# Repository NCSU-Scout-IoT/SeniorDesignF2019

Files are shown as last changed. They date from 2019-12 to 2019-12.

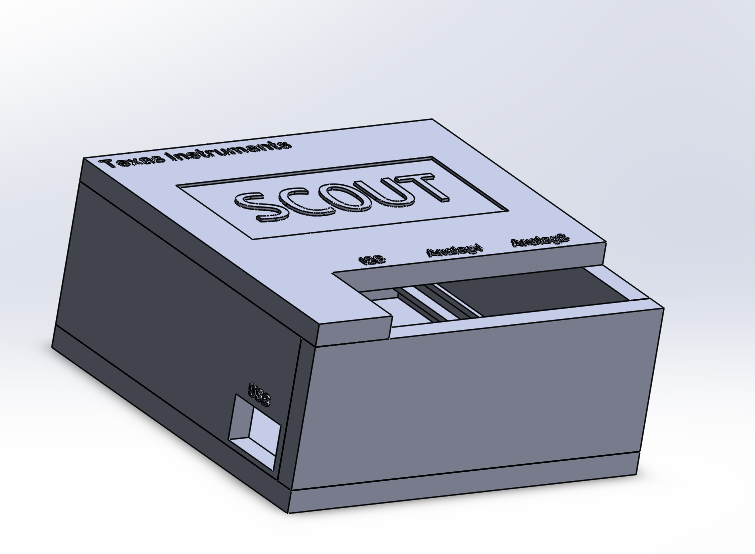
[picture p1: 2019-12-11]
Hardware Files/Enclosure Design/Picture.PNG

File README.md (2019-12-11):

# Scout IoT development kit
Table of Contents

Final Documents
- User Guides
  - QuickStart Guide
  - ESP32 AT Commands User Guide
  - Mobile Application User Guide
  - Software Guides
- Final Designs
  - Final Product Requirements
  - Final Test Plan with Results
  - Detailed Design Document
  - Final Bill of Materials
  - Final Product Price
  
Software Files
 - ESP32 Firmware
- Software Examples
- Mobile App Files

Hardware Files 
- EAGLE files
- Schematic and Board Layouts
- Enclosure 
  - SolidWorks Parts and Assembly
  - STL files

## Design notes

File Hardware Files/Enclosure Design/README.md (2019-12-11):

# Enclosure
Open STL files in Windows 3D Viewer

or

Open SLDASM in SolidWorks to view enclosure.

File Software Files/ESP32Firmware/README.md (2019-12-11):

# ESP32 firmware

File used in Arduino IDE

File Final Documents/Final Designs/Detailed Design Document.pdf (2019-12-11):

# Scout IoT Development Kit

## Sponsor: Mark Easley

Team Members: Emily Pigeon, Jacob Sparks, Caleb Snow,

## Qiang Yang

December 11, 2019

### Table of Contents

Abstract | 4
Background | 5
Requirements | 6
Architectural Diagrams | 7
User Operation | 8
Subsystems | 10
Power Supply Subsystem | 10
PCB Design/CAD Tool Selection | 12
Microcontroller | 15
Sensors | 17
Sensor Software | 18
ESP32-WROOM-32 | 19
Cloud Services | 24
Alternatives | 24
MQTT Protocol | 26
Mobile Application Builder | 27
Alternatives | 27
Conclusion | 29

### Table of Figures

Figure 1 - System Architecture | 7
Figure 2 - User Operation Diagram | 8
Figure 3 - Power Subsystem Block Diagram | 10
Figure 4 - Micro USB 2.0 | 11
Figure 5 - Block diagram for TI Buck Converter IC | 11
Figure 6 - Circuit diagram for power system | 12
Figure 7 - MSP430FR5994 library imported in Eagle | 13
Figure 8 - Eagle User Interface for Schematic Design Window | 14
Figure 9 - MSP430 Simplified Block Diagram | 15
Figure 10 - MSP430 Detailed Block Diagram | 16
Figure 11 - Sensor Subsystem Block Diagram | 17

Figure 12 - Grove Universal 4-pin connector | 17
Figure 13 - BoosterPack pinout | 18
Figure 14 - ESP32-WROOM-32 SMD package | 19
Figure 15 - Detailed physical dimensions of the ESP32-WROOM-32 | 19
Figure 16 - ESP32-WROOM-32 pinout | 20
Figure 17 - ESP32 detailed schematic | 21
Figure 18 - Wi-Fi software flowchart | 22
Figure 19 - Bluetooth software flowchart | 23
Figure 20 - MQTT flowchart | 26

## Background

As the demand for interconnectivity between devices grows, more and more developers are entering the IoT (Internet of Things) market. These developers are often looking for an IoT kit that can allow them to enter in to this market as fast as possible, as cheaply as possible, and with less and less technical knowledge. This design offers developers a relatively inexpensive and simple way to develop IoT-capable devices with only some embedded C programming skills required.
For developers that have some experience using either TI BoosterPacks or Seeed Grove modules, this kit will stand out as it can accept sensors in either format. This kit can utilize analog Grove sensors, digital Grove sensors, and TI BoosterPacks simultaneously. This gives the developer the ability to choose from several hundred different sensors and a vast amount of combinations. Accepting both the BoosterPack and Grove module formats gives this design more versatility, without requiring any more technical experience.

## Requirements

version 3.1

### 1. General Functional and Mechanical Requirements

1.1. Product MUST have an open-source PCB layout and bill of materials
1.2. Product MUST have a Quick Start Guide paper insertion with a pinout diagram, instructions on how to obtain software demos and PCB layout, and a list of materials.
1.3. Product MUST transmit sensor data via Wi-Fi to cloud service at no less than 1Mbps
1.4. Product MUST transmit sensor data via BLE, at least 1Mbps, to the mobile phone app
1.5. Product MUST cost under $50 to manufacture
1.6. Product MUST include a plastic chassis with tool-less assembly and disassembly

### 2. User Interface Requirements

2.1. Product MUST have a user-programmable LED and push button
2.2. Product MUST have an LED to display Wi-Fi connection status
2.3. Product MUST have power status LED

### 3. Hardware Requirements

3.1. Product MUST use micro-USB connector for power
3.2. Product MUST use TI MCU
3.3. Product MUST have clear silkscreen labeling of important board markings for users
3.4. Product MUST have headers for hardware debugger (MSP-FET)
3.5. Product MUST include 3 Seeed Grove connectors, 2 designed for analog signals and 1 for digital I²C signals

### 4. Software Requirements

4.1. Product MUST have at least 5 code examples with documentation
4.2. Code examples MUST be available for Code Composer Studio
4.3. Code examples MUST include blinking LED, button input, and wireless communication initialization
4.4. Cloud Service MUST show data from all sensors and define which sensor ports are not in use.
4.5. Mobile Application MUST show real-time sensor readings

## System Drawing

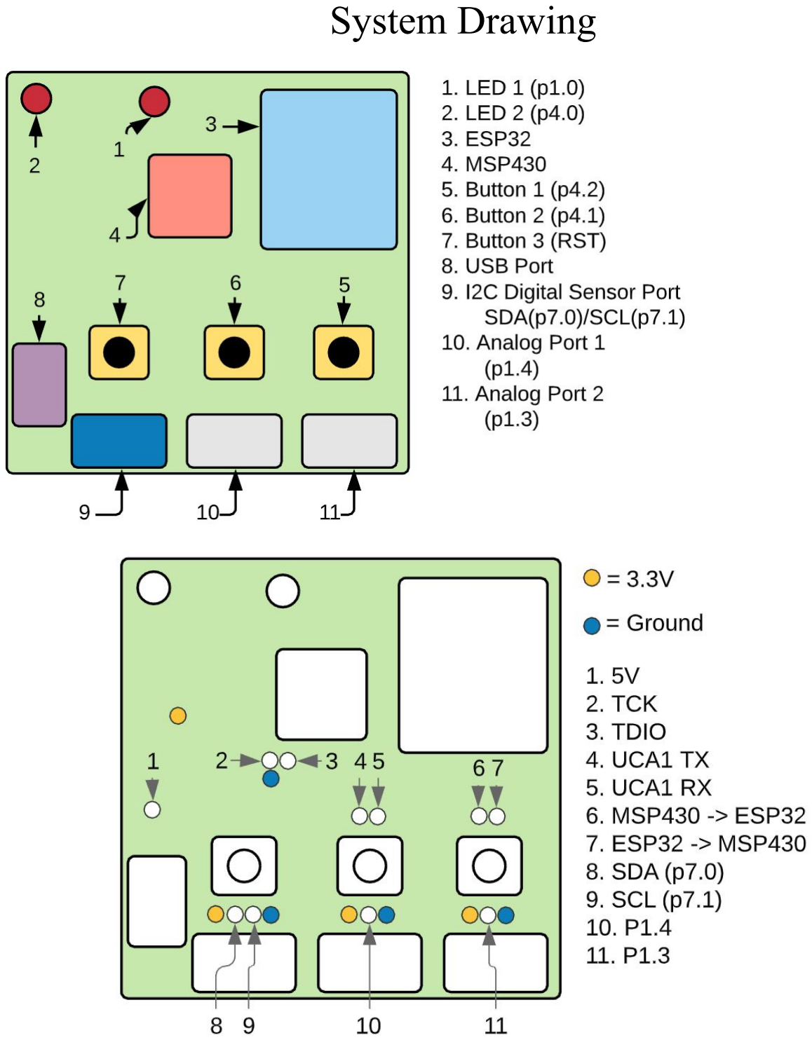
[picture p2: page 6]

## Operational Diagram

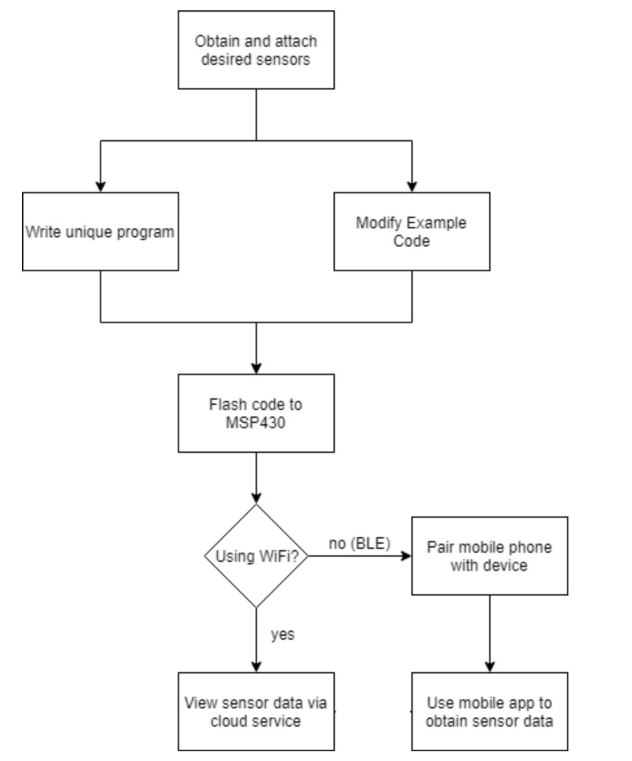
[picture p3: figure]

Since this kit is aimed at aspiring developers, the user operation will require a limited knowledge of embedded systems coding. We will be providing example code with functions that connect to a Wi-Fi network and send data over either connection, but for specific applications beyond these simple starting points, some expertise will be required.
The user will view and analyze sensor data via our chosen cloud service, Microsoft Azure IoT Hub. The sensor data could also be analyzed on the chip, and actions related to the specific application could be taken without direct user intervention, e.g. using a general-purpose I/O to activate an actuator.

## Detailed System Block Diagrams

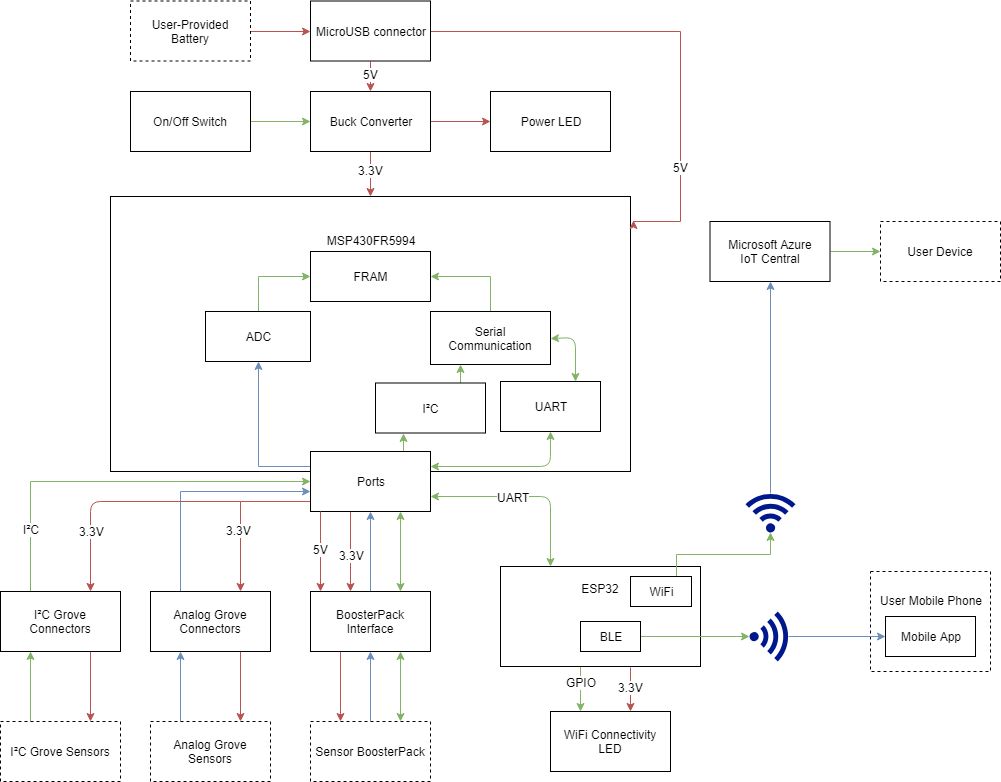
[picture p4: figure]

The two key blocks in our architecture are the MSP430 microcontroller and the ESP32 network processor. Part of the reason we decided on the ESP32 can be seen in our diagram - ease of connection. Only a single UART connection will be necessary for the MSP430 to communicate with the ESP32 and, therefore, the cloud service and user. As can be seen in the legend, green arrows are digital information, either in the I²C format or UART on our device, and in other forms on the user devices. Red arrows represent power that our power system will provide for and blue arrows show analog signals, either sensor data to be sampled by the MSP430’s analog-to-digital converter (ADC) or wireless signals.

Blocks shown with a dotted border are subsystems that are critical to the full function of our device but will be provided by the user. Any power source that conforms to the MicroUSB standard could be used in place of a battery, provided it can fully supply the power required. This means that a user could instead use an AC/DC converter to power the device from the wall if they were so inclined.
The sensor choice is up to the user, and we provide two methods of connection: Grove sensors and BoosterPacks. The sensors will communicate with the MSP430 either through an analog signal or a serial digital communications protocol. Two of the Grove connectors will use the I²C protocol and the other two will send an analog signal to be processed by the MSP430’s ADC.
The ESP32 will forward sensor data to Microsoft Azure where it will be processed and visible to the user through any device. The forwarding will either happen through Wi-Fi, where it will connect directly to Microsoft Azure through the Internet, or through Bluetooth Low-Energy (BLE) via a mobile phone application.

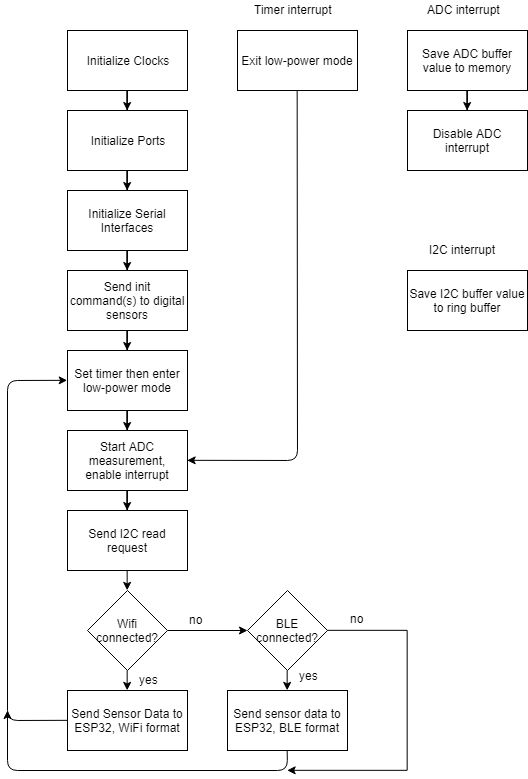
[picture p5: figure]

The overall format of the software
provided as an example is a loop wherein the
device stays in a low-power mode for as long as possible. After initialization, the main loop consists of enabling interrupts, getting sensor data through those interrupts, forwarding the data to the ESP32, then reentering low-power mode.
The messages sent to the ESP32 will depend on whether the device is connected to a wireless network with access to Microsoft Azure or paired via Bluetooth to the mobile app.

## System Design and Component Selection Alternatives

Microcontroller

Alternatives to the MSP430FR5994 include the MSP432P401Y, a more expensive 32-bit MCU with an ARM Cortex CPU and a clock of up to 48MHz, and the less expensive MSP430FR2355. We chose the MSP430FR5994 due to its value and ability to perform the functions necessary for an IoT development kit. The larger number of ADC and I²C channels and larger memory made it the ideal choice when compared to the lower-priced FR2355. The MSP432401Y’s higher-powered CPU would not be fully utilized by our applications, and since it had almost equivalent I/O capabilities with the FR5994, it was ruled out.

Microcontroller | Price | I²C | ADC channels
MSP430FR5994 | $3.60 | 3 | 20
MSP430FR2355 | $2.40 | 2 | 12
MSP432P401Y | $5.40 | 3 | 12

Network Processor

Alternatives to the ESP32 included the TI CC3100MOD, a Wi-Fi only network processor made with cooperation with MSP430 microcontrollers in mind. However, its higher price, lack of Bluetooth capability, and more complicated proprietary API made the ESP32 the better choice. Espressif also makes cheaper network processors such as the ESP8285. These would have served well for our application if Wi-Fi had been our only method of communication, but the added benefit of Bluetooth made the ESP32 worth the extra cost.
Network Processor | Cost | Capability | Ease of use
Espressif ESP32 | $3.80 | Wi-Fi + Bluetooth | AT Commands
TI CC3100MOD | $6.99 | Wi-Fi | TI API
Espressif ESP8285 | $1.80 | Wi-Fi | AT Commands

Cloud Service

Cloud Service | Pros | Cons
Microsoft Azure IoT Hub | ● Cost: Free to sign up ● Made to be simple and easy to use for people with little cloud experience ● Provides a GUI with charts for incoming data ● Many online resources on how to set up | ● No specific online documents relating to ESP32 from Microsoft ● Less code samples
Amazon Web Service FreeRTOS | ● Partners with Espressif ● Good online documentation concerning the ESP32 ● Includes support for BLE Mobile ● Many code examples from Amazon | ● Price: Charges for data transfer, otherwise free to use ● Code intensive
Google Cloud IoT Core | ● Partners with Espressif ● Thorough overall documentation ● Many code examples from Google | ● Price: Charges by volume of data, up to 250MB free ● No online documentation about the ESP32 from Google ● Code intensive

Amazon Web Service’s FreeRTOS is a contender because Amazon is the most popular company on the market providing cloud services, which means it is well documented and will likely have many available resources for us to use in development, as well as the consumer. This particular service is directed specifically at IoT developers working with MCUs. A major benefit of this service is the BLE mobile app, but this service is still in beta testing. There is an online guide to set up service on an ESP32 Development Kit, and it is very thorough, but it also shows how labor intensive it is. The price could also pose an issue, as most of what we will be using the service for is data transfer from the device to the cloud, which means this service could be costly to us. The total cost includes many different aspects of how we use the service, so price estimation would be very difficult. In addition, during the research of this service, we could not find any examples of how the data would be displayed on the PC client, which implies that is something we’d set up ourselves. Overall, while the service is very popular and well documented, it is meant for people with a lot of experience setting up a cloud service, and we do not have enough time or resources to dedicate to using this software.

Google Cloud’s IoT Core is also a contender. Google is another reputable company but is not as established as Microsoft or Amazon when it comes to IoT applications. The service itself is extremely well documented, with many code samples in many different languages. However, there is very little documentation to be found concerning the ESP32 specifically anywhere online, and none was found from Google. Pricing is also a concern. Google charges for every message sent after a limit of 250 MB is exceeded. The IoT Core from Google would also need to use Google’s IoT Pub/Sub service, which we would also be charged for. Overall, similarly to AWS FreeRTOS, this service would be difficult to set up and could be expensive.

Our final contender is Microsoft Azure’s IoT Hub, which is Microsoft Azure’s IoT cloud service that is comparable to the previous two choices. IoT Hub can handle connection to the device, neatly displaying sensor data in graphs, and creating rules and actions concerning sensor data, such as sending an email if a sensor is tripped if used with Hub Solutions. Pricing is also very simple, as it is free to sign up with $200 credit. Considering that we will only be using one device, and likely will be under the limit, we will likely be able to use this service either free or very cheaply. Unfortunately, there isn’t documentation from Microsoft concerning the ESP32 specifically, however there are general guides to aid set up. There are thorough online guides about how to set up the software itself as well. Another potential issue with this software is that it is more limited than the previous examples, so there is not much we can control. After
comparing these cloud services, we selected Azure’s IoT Hub for its apparent ease of use and simple pricing.

Mobile App Builder

To provide clients with examples of setting up Bluetooth from the ESP32, we must select a simple mobile application builder to debug our software. To do this, we must use a quick and easy mobile application builder that can communicate through Bluetooth and accurately read back sensor data. There are many options on the market for mobile app builders, but it is important that we find one with many available online resources and support.

Mobile App Builder | Pros | Cons
Thunkable | ● No coding required ● Online tutorials with the ESP32 ● Free for public projects, offers special education prices ● Works with both iOS and Android ● Public library of projects ● Supports BLE | ● Reports of bugs ● ESP32 example uses Arduino IDE
Evothings Studio | ● Supports BLE ● Works with Android and iOS ● Completely free and open source ● Extensive BLE documentation | ● Coding in HTML5 ● No specific ESP32 examples
Android Studio | ● Reliable company ● Extensive BLE documentation ● Coding in Java or C/C++ ● Completely free | ● No specific ESP32 examples ● Only supports Android

We chose Thunkable as our sample mobile application. Because this software requires no coding, it will be much quicker to get up and running when our ESP32 is ready to be debugged. Android Studio and Evothings Studio both require the application to be built from code, which will make debugging more difficult because bugs could exist in either our mobile application or our development kit. Also, Evothings Studio requires software to be done in HTML5, which none of us have experience with. Thunkable also has a public library of apps that other developers that use the software have created. Within this library are examples of a BLE application that connects specifically to the ESP32. While both Evothings and Android have very thorough documentation of how BLE can be implemented on their platforms, neither has examples that relate to the ESP32 specifically. Finally, Thunkable, as well as Evothings, creates applications that can be used on both iOS and Android, which will allow our code to be more thoroughly tested and easier to develop. Android Studio, while being a reliable company, is not available on iOS which means we will have to have an Android phone to test.

## Hardware Design

PCB Design/CAD Tool Selection

The CAD tool chosen for the schematic and PCB design of this project is Eagle. Eagle was chosen from the selection of tools including: Altium, KiCad, Eagle, OrCad, and DipTrace. A major selection criteria in this process was design files/footprint/symbols accessibility. Creating these from scratch would be much less time-efficient than finding them online and importing them into our design tool. Eagle offered the best online support of the tools mentioned and can import files directly from the UltraLibrarian tool on Texas Instruments’ website. Any other components can be sourced from the many websites that offer libraries for Eagle.
Another consideration was the user interface. The more intuitive the interface is, the less time consuming it will be to begin using the CAD tool. Eagle’s user interface is as simple and intuitive as any of the other choices. The Eagle schematic editor includes:
- Links to a library
- Electrical rule check
- Netlist generation
- Forward/Back annotation between schematic and PCB (keeps things in sync when making changes in one or the other)
- Schematic hierarchy for the design organization
- User access to define many things like nets, wire width, clearance, etc.

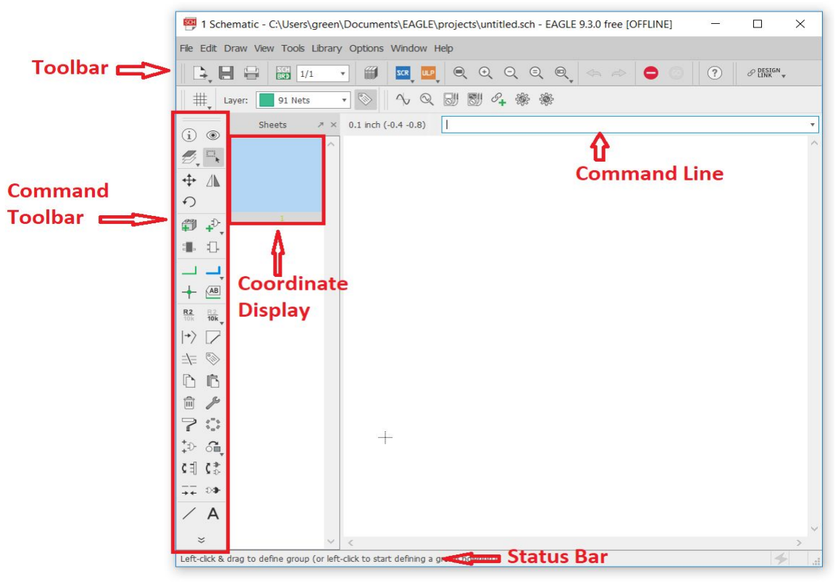
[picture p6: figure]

Figure 8 - Eagle User Interface for Schematic Design Window

Basic Circuit Design

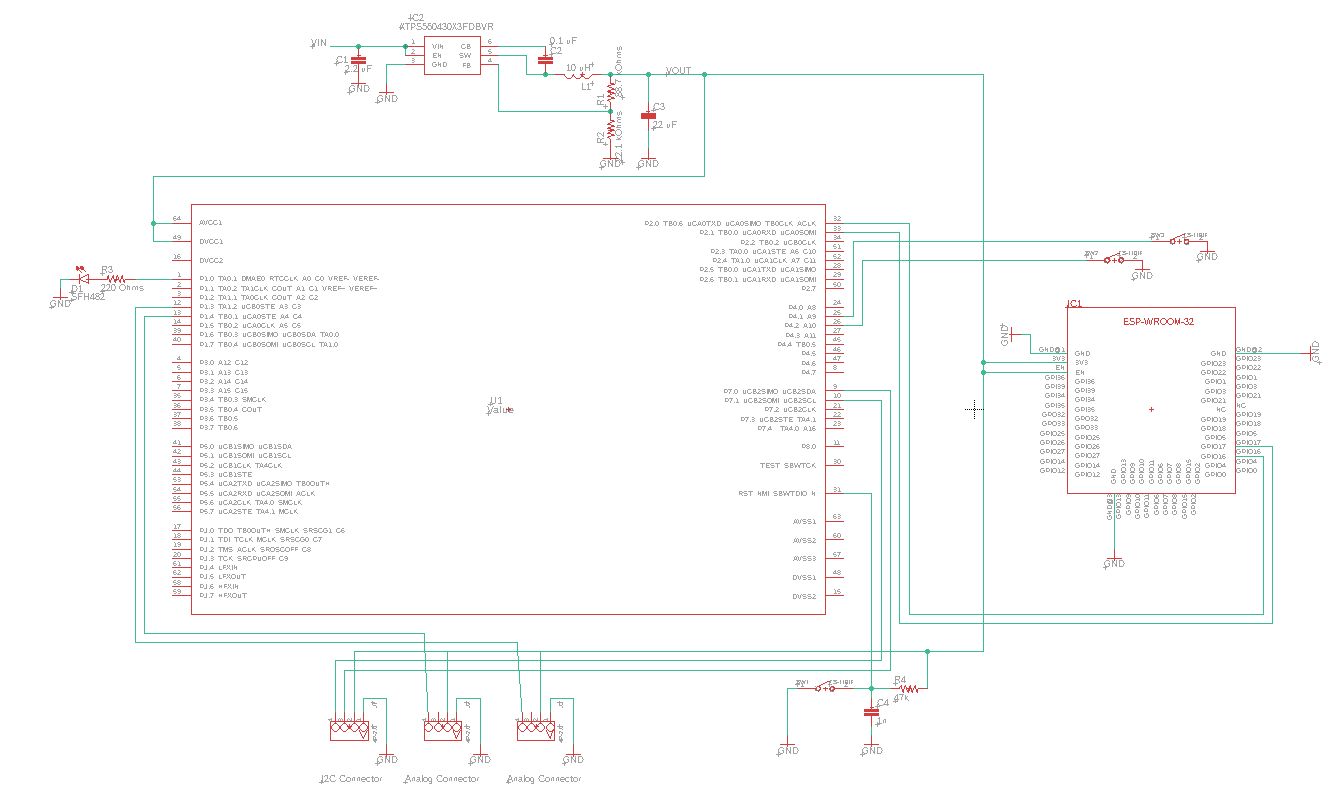
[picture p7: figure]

Figure 9 - Schematic Design
Depicted above is the first iteration of the circuit schematic. This schematic includes 2 analog grove sensor connectors, 1 digital grove sensor connector, 2 I/O push buttons, a reset button circuit, a programmable LED circuit, the power supply circuit, the ESP32 surface-mounted chip, and the MSP430 64-pin surface-mounted chip. This schematic is identical to the final design except that the power supply circuit was replaced with a through-hole buck converter module to save space and for fast prototyping. The intention was to replace the less efficient and more expensive power supply module with an improved power supply circuit and buck converter IC on the board, however this was not accomplished. The microUSB port did not have a schematic element and was therefore not included in the schematic. However it can be seen on the final PCB as illustrated in figure 10.

Final PCB

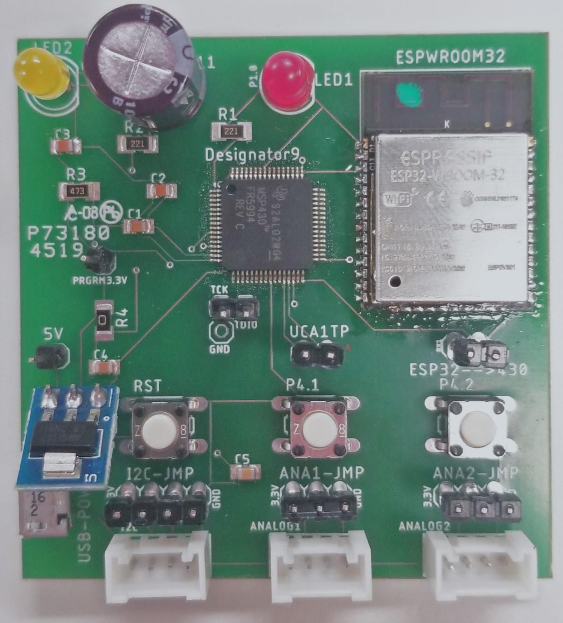
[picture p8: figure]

Figure 10 - Final PCB
The final PCB is illustrated in figure 10. The dimensions were 2.35” by 2.3”. The substrate for the PCB was FR-4. Anywhere possible, surface mounted components were favored over through-hole to save space and costs. The labeling of components and headers was very important for this design, as its target audience will include novices. Keeping not only the components labeled but also labeling what pins on the MCU they are connected too will help users when flashing the board, intercepting communication between elements, or wiring boosterpacks and other non-grove sensors. The PCB was manufactured by Advanced Circuits and its price was $99 for 3 boards. This equates to one board costing $33. This price would be much less when manufacturing in bulk.

## Subsystem Block Diagrams

Microcontroller

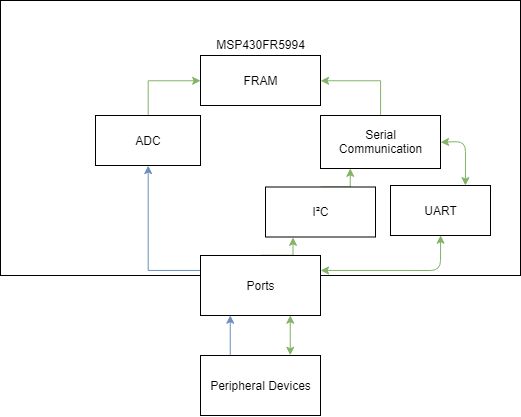
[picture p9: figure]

Figure 9 - MSP430 Simplified Block Diagram
The microcontroller we have chosen for the device is the MSP430FR5994. It has 256kB of Ferroelectric RAM (FRAM), which is faster and more resilient than traditional flash memory, and unlike DRAM, is non-volatile, meaning it retains its values even without power. Having a healthy amount of memory will be important for storing sensor data if an Internet or Bluetooth connection is temporarily unavailable.

The MSP430 we have chosen has up to 20 ADC channels and 4 I²C channels, although the package we are using will only have 3 I²C ports available. A more detailed view of the full capabilities of the MSP430 can be seen below.

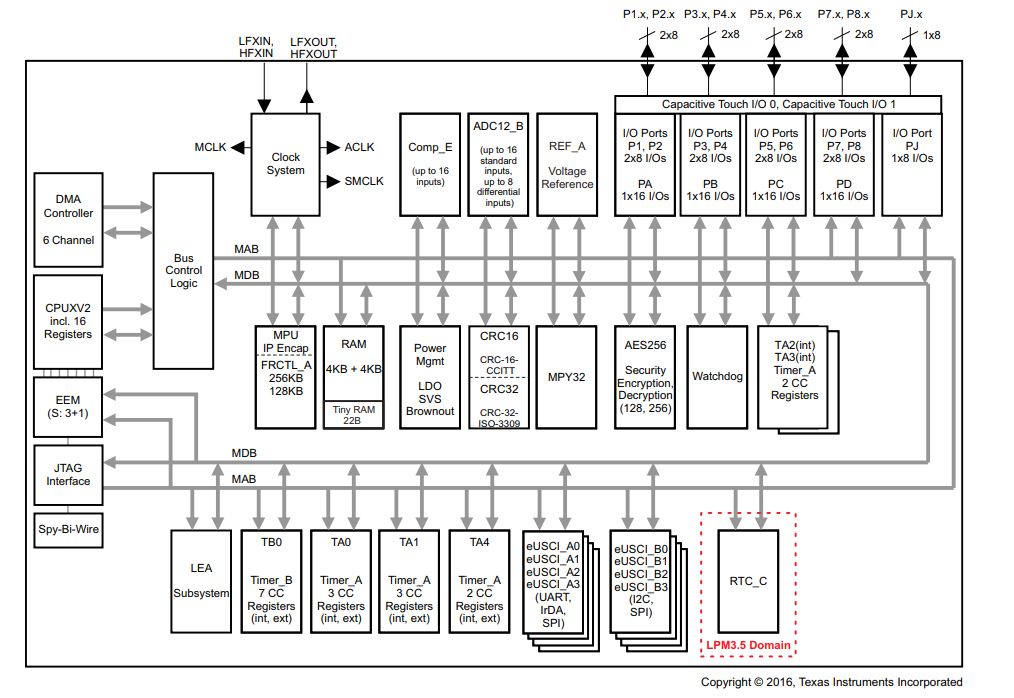
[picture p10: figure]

Figure 10 - MSP430 Detailed Block Diagram

Sensors

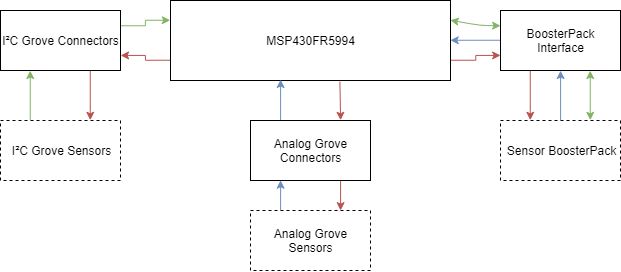
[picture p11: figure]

Figure 11 - Sensor Subsystem Block Diagram
The device will include four Seeed Grove connectors. We chose this sensor ecosystem due to its popularity and simplicity. Each connector only has four pins, making the hardware design straightforward. Two of our connectors will be analog and two will use the I²C digital protocol.
Pin | Function
pin1 | Primary Analog In / I²C clock
pin2 | Secondary Analog In / I²C data
pin3 | VCC
pin4 | GND

Figure 12 - Grove Universal 4-pin connector

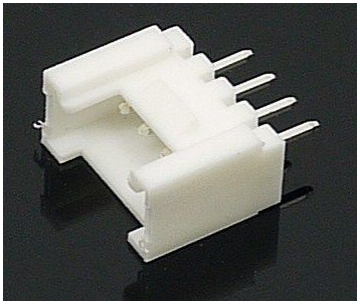
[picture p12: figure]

The second method a user will have to connect sensors will be the BoosterPack interface on the board. These pins will be capable of accepting any TI BoosterPack compatible daughterboard or any jumpers the user might use instead. We decided on the BoosterPack ecosystem due to its maturity, availability of documentation, and ease of use in our CAD tool.

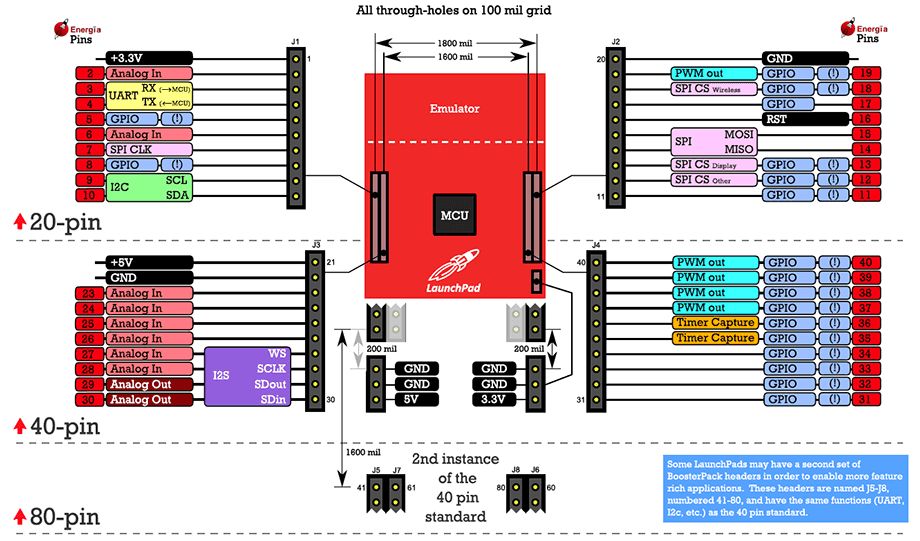
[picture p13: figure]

Figure 13 - BoosterPack pinout

ESP32-WROOM-32

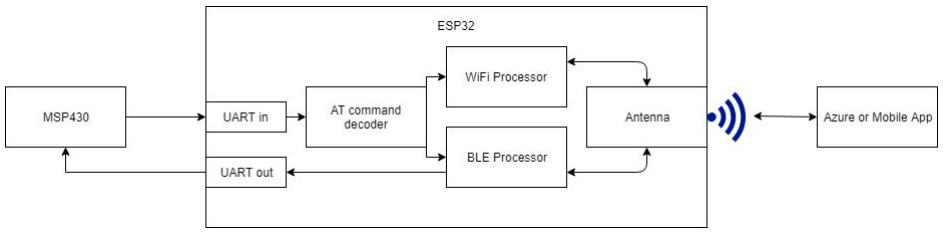
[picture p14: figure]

The Wi-Fi and Bluetooth module that we have chosen for this project is the Espressif ESP32-WROOM-32. This module provides Wi-Fi, Bluetooth and Bluetooth MCU capabilities. It includes key components for the printed circuit board design such as a receive amplifier for low-noise, antenna switch, and different filters for different signals.
The ESP32-WROOM-32 provides different power modes and consumes less power than other chips. The sleeping current is less than 5μA and in some applications, the ESP32 can be active only when it is needed. It has two CPU cores which can be controlled individually and the clock frequency of the CPU ranges from 80 MHz to 240MHz. The duty cycle of the clock is low so that the energy being used will be reduced.

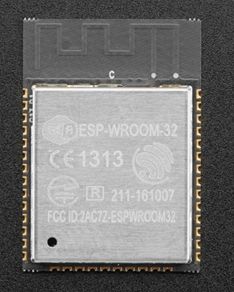
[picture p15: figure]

Figure 14 - ESP32-WROOM-32 SMD package

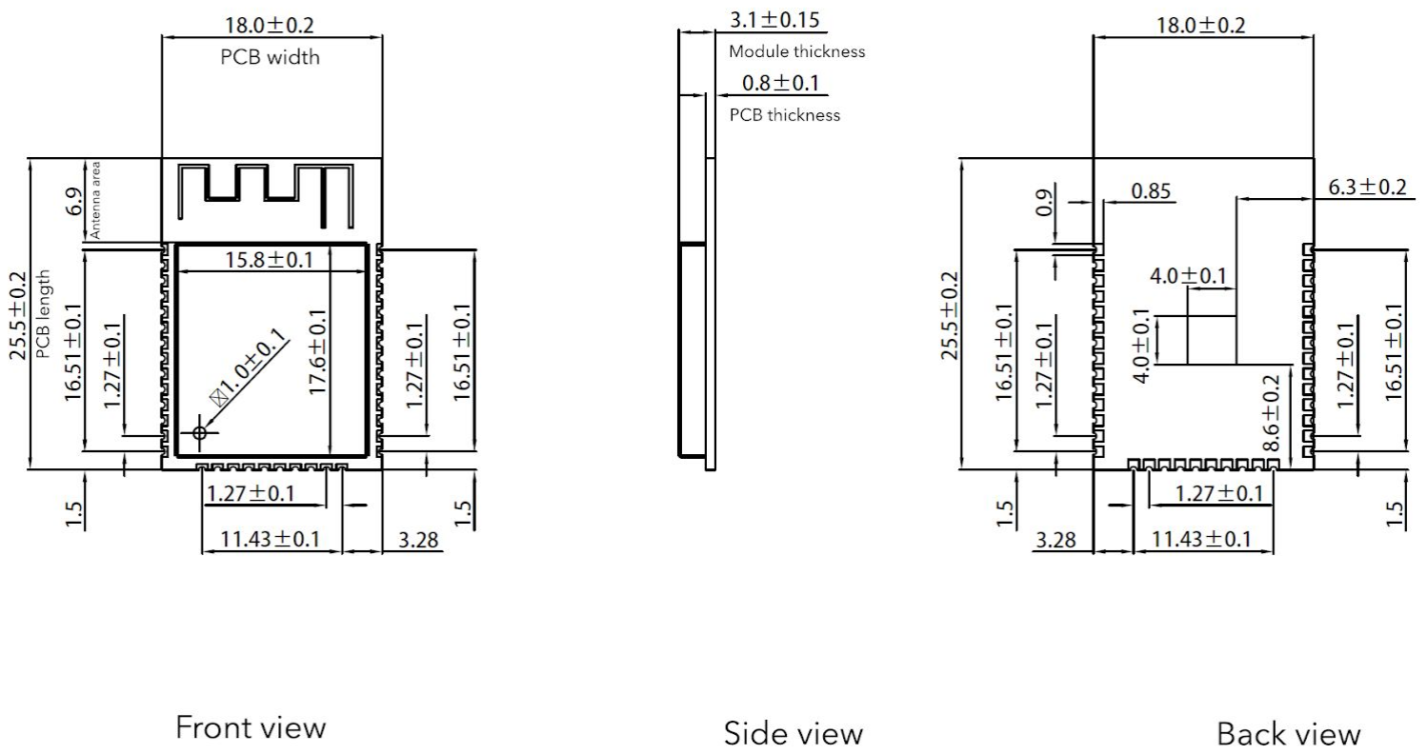
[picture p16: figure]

Figure 15 - Detailed physical dimensions of the ESP32-WROOM-32

The ESP32-WROOM-32 operates under a voltage between 2.7V to 3.6V under the average current of 80 mA. It has 38 pins including five strapping pins. The five strapping pins are MTDI, GPIO0, GPIO2, MTDO, and GPIO5. Those strapping pins allows the software to read the value from the “GPIO_STRAPPING” register.

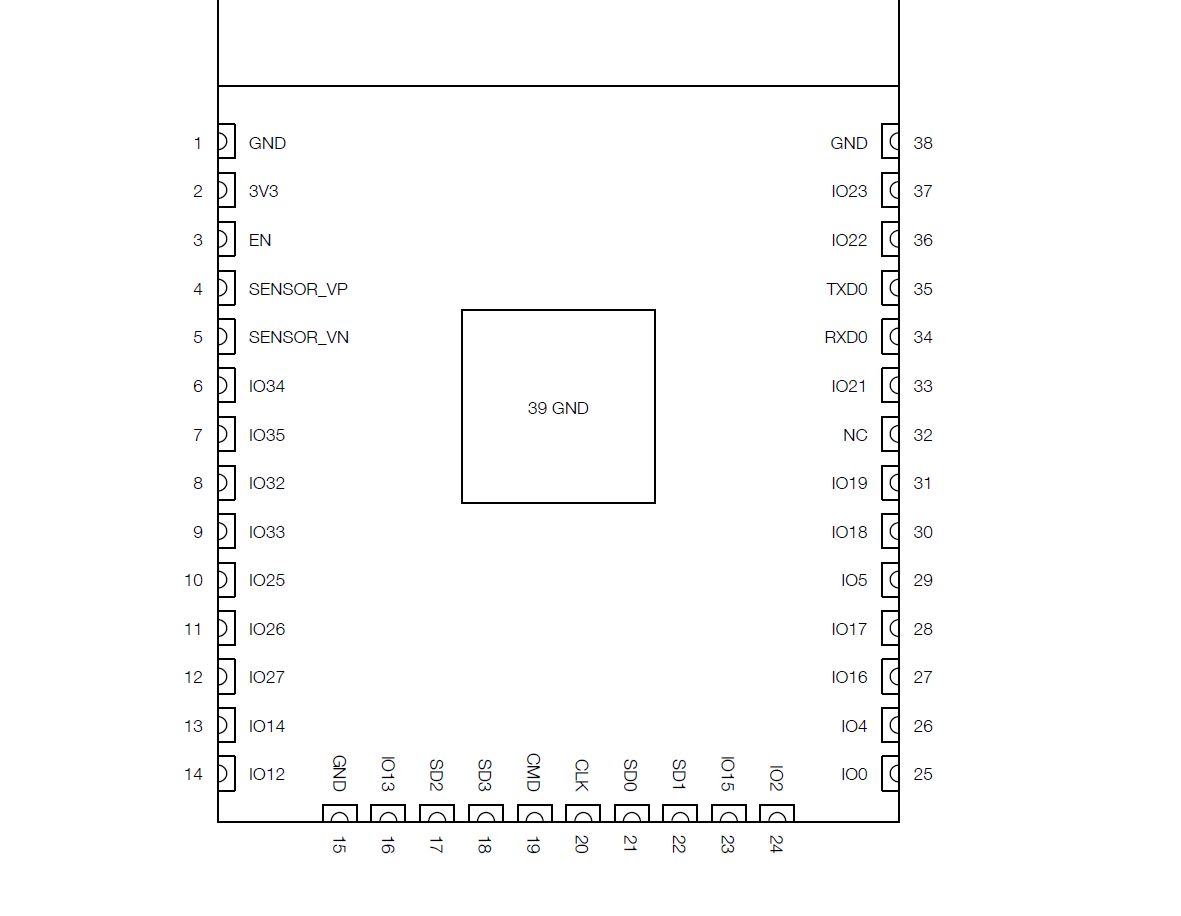
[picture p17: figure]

Figure 16 - ESP32-WROOM-32 pinout
For more detail, the schematic of the ESP32-WROOM-32 is shown below.

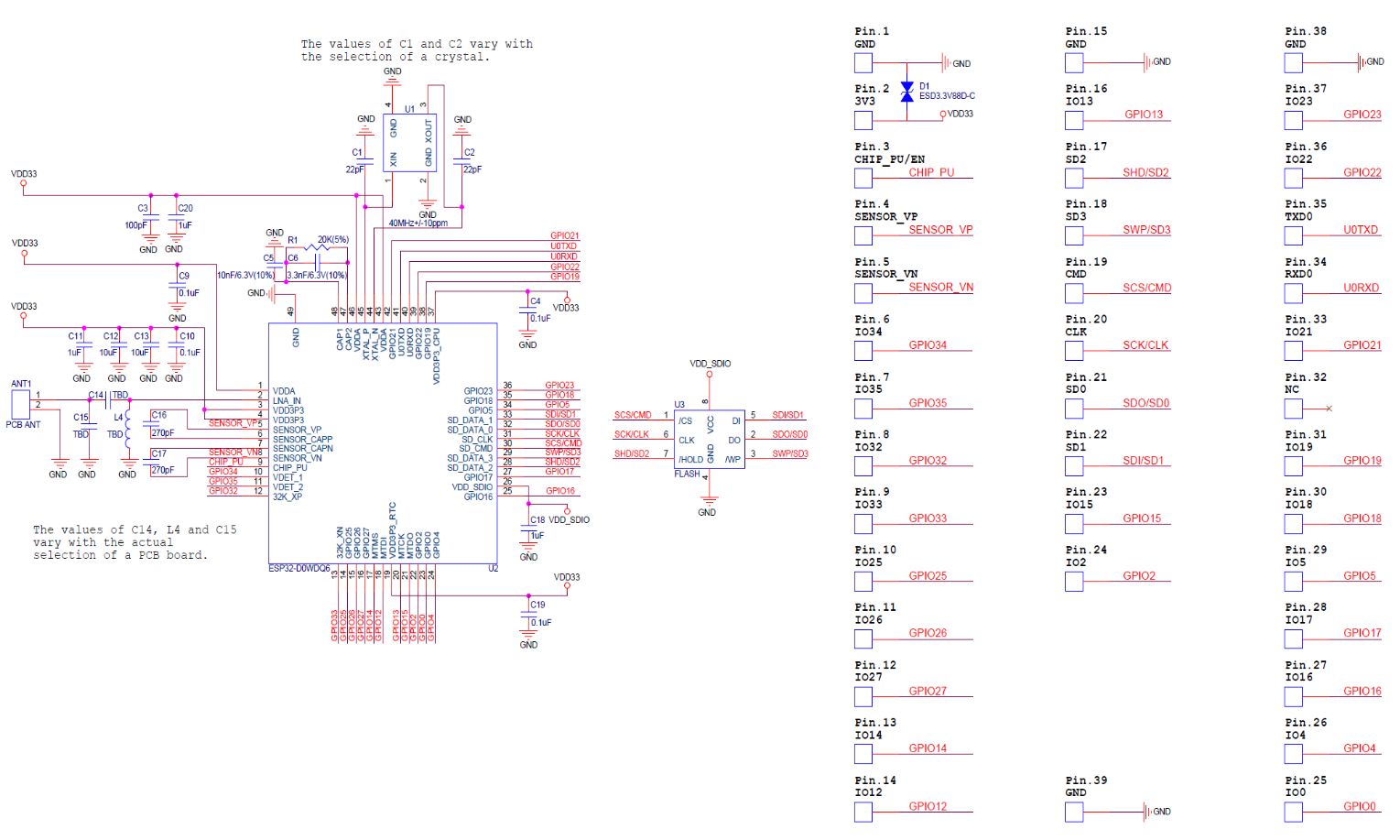
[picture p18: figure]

Figure 17 - ESP32 detailed schematic

Regarding the Wi-Fi portion of the chip, the standard is 802.11 b/g/n and it supports 2.4 GHz band to 2.5 GHz band. The speed of transporting the data can reach up to 150 Mbps and the output power at antenna can reach up to 20.5 dBm. The security types which are provided by the software of this chip are WPA, WPA2, WPA2-Enterprise, and WPS. Those can help the future developer who use our design to protect their data privacy.
The Bluetooth protocols which is provided by this module are Bluetooth v4.2 BR/EDR and BLE specification. For the radio signal, it provides NZIF receiver with -97 dBm sensitivity and uses transmitter with class-1, class-2, and class-3 power class capabilities. In terms of the audio signal, it provides CVSD and SBC.
Our product requires a cloud service for the client to view data from the sensors on the board. We need a cloud service that is able to receive data from our ESP32 and display it on a PC. We would prefer that our cloud service is simple and quick to set up and operate, as well as offers good online documentation and resources. There are many cloud service providers that are currently available to the IoT market. Three of the most popular companies are Amazon Web Services, Microsoft Azure, and Google Cloud. Each of these companies have multiple solutions on the market directed at IoT developers. Our ideal solution would be cost effective, simple to implement on a PC, and would be well documented to work with the ESP32.

Azure IoT Hub

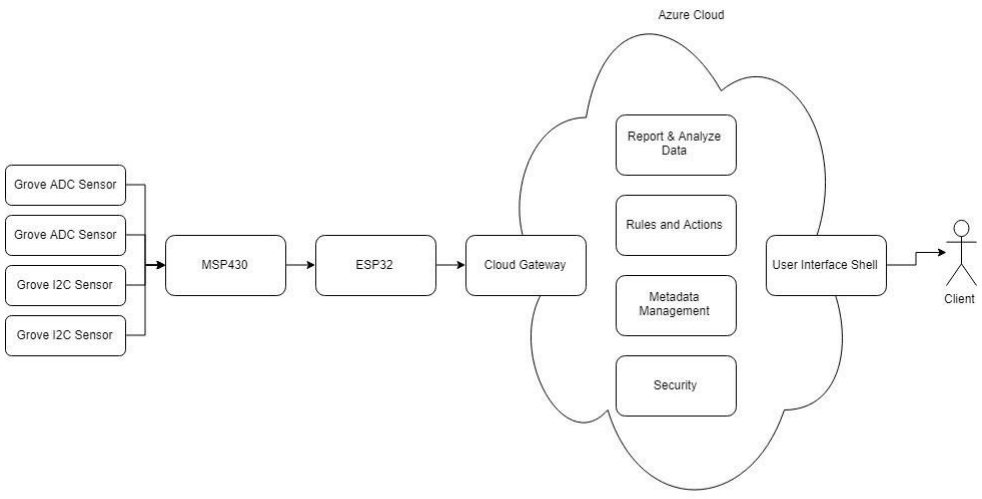
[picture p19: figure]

Figure 20 Azure Cloud and Incoming Data
As far as how the cloud works, we are most interested in incoming data, so that we can assure the client is receiving accurate data reports with our software. Data will come in from the sensors to the MSP430. The MSP430 will send the data to the ESP32, where it will be transported through WiFi to the cloud gateway. There, IoT Hub will handle reporting and analyzing data, rules and actions regarding data that will be set by the user, as well as metadata management and security. IoT Central’s user interface shell is an HTML5 application that allows the user to see graphs and charts relating to the incoming data as well as set different rules and actions.

## Software Design Documentation

Sensor Software

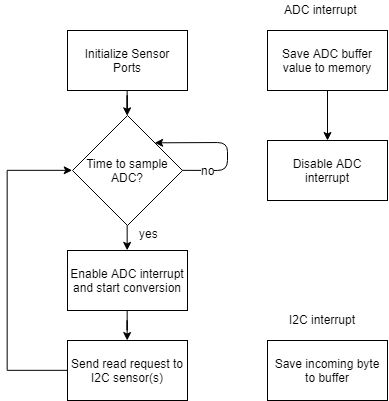
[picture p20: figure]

Our sensor software will consist of a simple timer-driven interrupt pattern. When the period given by the specified sampling frequency has elapsed, the MSP430 will exit low-power mode and enable the analog-to-digital conversion and I²C interrupt functions. Within these functions, all the sensor data will be saved to memory (FRAM) before they are ready to be transmitted.
This type of interrupt-based algorithm will allow the device to stay in a low-power mode for as long as possible, saving battery life if a battery is used. In the MSP430’s active mode, it draws 120μA/MHz. At the default 8MHz, the current draw is 960μA, making the power draw 3.186mW (P = IV where V = 3.3V). When in low-power mode 1, the current draw is only 40μA at 1MHz, making the power draw only 0.132mW, or 4.14% of the active state power consumption.
The power savings become even more apparent when comparing the different operating modes of the ESP32. When active, i.e., transmitting, receiving, or listening, the ESP32 will draw up to 240mA typically. That translates to 0.792W of power, which is significantly more than any other device on the board. In the ESP32’s light-sleep mode, which it would be kept in unless actively transmitting, it draws 0.8mA of current and thus 2.64mW of power. This is only 0.33% of the active power draw, making the incorporation of switching between states critical.

Networking Software

The following flow chart shows how the Wi-Fi will work in the design cycle. The ESP32 will first detect if the specified network is available. If the network is available, it will connect to it and receive signal from user devices. When it is time to send the data, it will send the data to the cloud service, Microsoft Azure. The following flow chart shows how the Wi-Fi software will work in the design cycle.

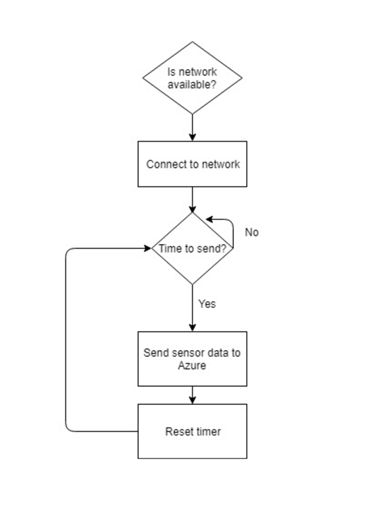
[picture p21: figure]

In our design, the user needs to press the pairing button and then the chip will have a scan for devices. When the device is detected, it will try to connect to the user’s available equipment. If the device is not available at that time and the connection time is out, it will go to the initial state and wait for the button to be pressed. On the other hand, if the device is available, it will pair to the device. After successfully connected to user equipment, it will receive the data from user device or sensor and when it is the time that the data needs to be sent, it will send the data to the phone. The following flow chart shows how the Bluetooth software will work.

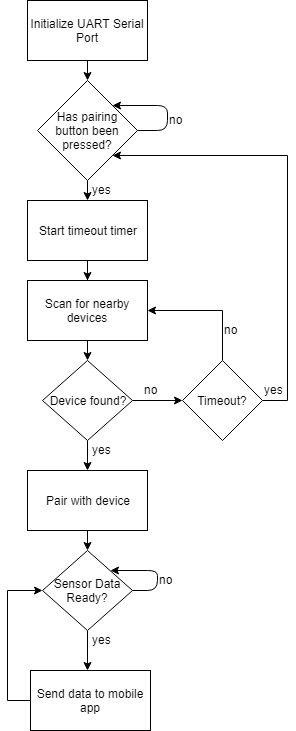
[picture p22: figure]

MQTT Protocol

Messaging Queuing Telemetry Transport, or MQTT protocol, is a very popular IoT protocol that we will be using for both WiFi and Bluetooth communications. It consists of a broker, a server that collects and distributes data, and clients, devices that collect or receive data, in our case the mobile app, cloud service, and sensors. The type of data collected by a sensor is called a topic. Clients like the mobile app and cloud service will ‘subscribe’ to topics, and the sensors will ‘publish’ data. The broker handles where published content goes.

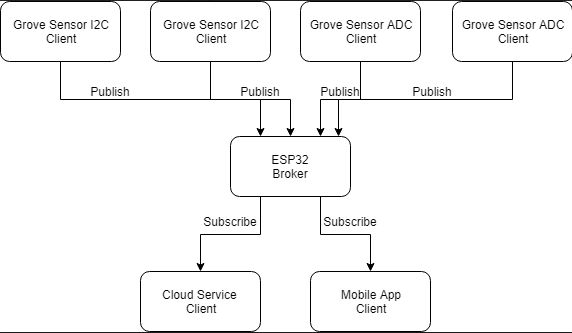
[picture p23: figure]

Figure 21 - MQTT flowchart

## Enclosure Design

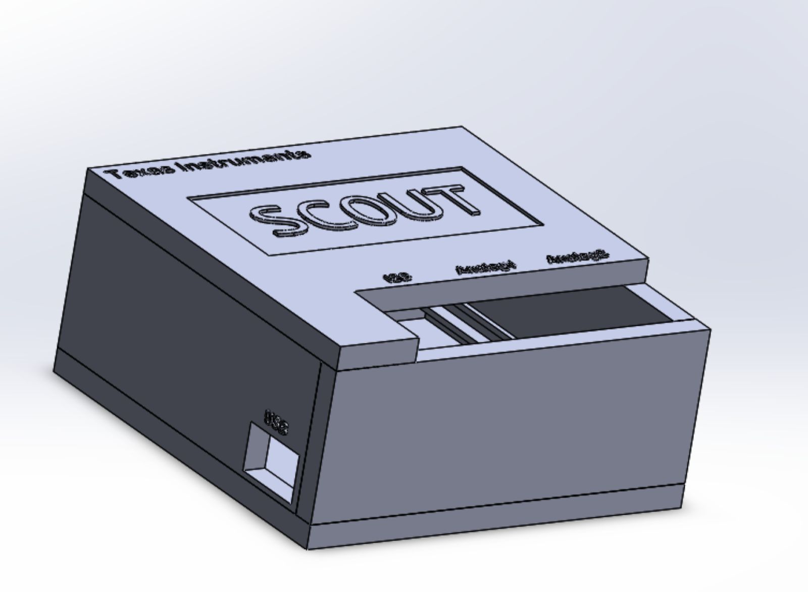
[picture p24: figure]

## Conclusion

In this document, we have outlined the main systems that will support the Scout IoT DevKit. This kit is meant to be simple for the user to use and turn into a functional product. Thus, the Scout must prove to be a reliable system that is thoroughly documented and open source. The kit consists of a microcontroller and Wi-Fi/Bluetooth module, 3 Grove sensor connectors and Texas Instruments BoosterPack capabilities. These core features will allow the consumer to easily plug in their own sensors and additional BoosterPacks, and use our code library to easily read sensor data and set up two way communication through Wi-Fi and BLE. The consumer will be able to create their own IoT solutions without having to build from scratch, while still further accelerating the growth of the IoT market.

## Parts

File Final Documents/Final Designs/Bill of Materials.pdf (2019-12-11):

Scout IoT DevKit Bill of Materials

- (1) Printed Circuit Board - $33
- (1) 10µF 400V Aluminum Electrolytic Capacitor - $0.84
- (1) 0 Ohms Jumper 0.25W, 1/4W Chip Resistor 1206 - $0.10
- (1) MSP430FR5994 64-pin Microcontroller - $7.77
- (3) Omron tactile switches, B3F-1000 - $0.25 ea
- (3) Seeed Grove Connectors - $0.15 ea
- (1) 47 Kohm resistor, surface mounted - $0.16
- (2) 220 Ohm resistor, surface mounted - $0.16 ea
- (1) 1 nF capacitor, surface mounted - $0.14
- (4) 100 nF capacitors, surface mounted - $0.10 ea
- (1) red LED - $0.22
- (1) yellow LED - $0.21
- (1) ESP32 WiFi IC - $4.50
- (1) AMS1117 Buck Converter Module - $2.00

Total Cost for Prototype: $50.86

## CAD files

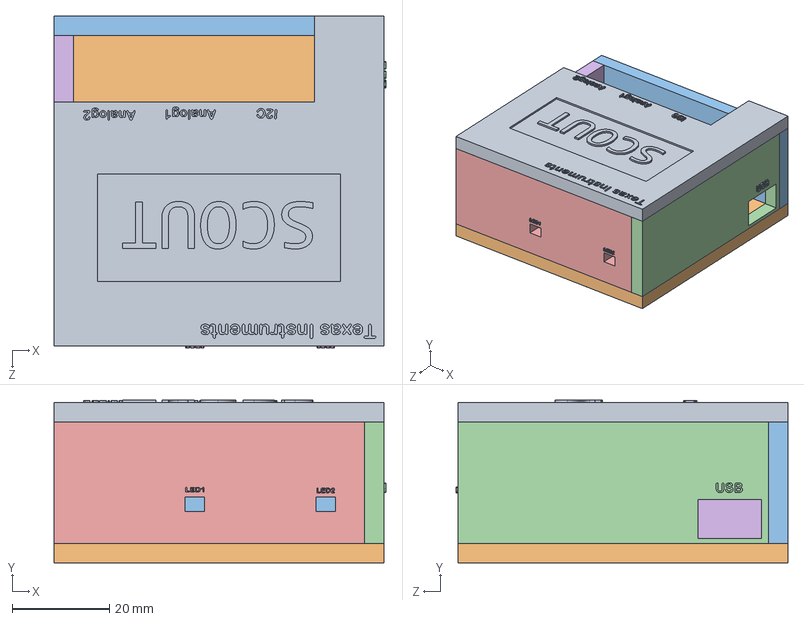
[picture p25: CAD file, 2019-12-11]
Hardware Files/Enclosure Design/Enclosure.SLDASM
68.4 x 33.5 x 68.4 mm
Top
Bottom
Side4
Side3
Side2
Side1

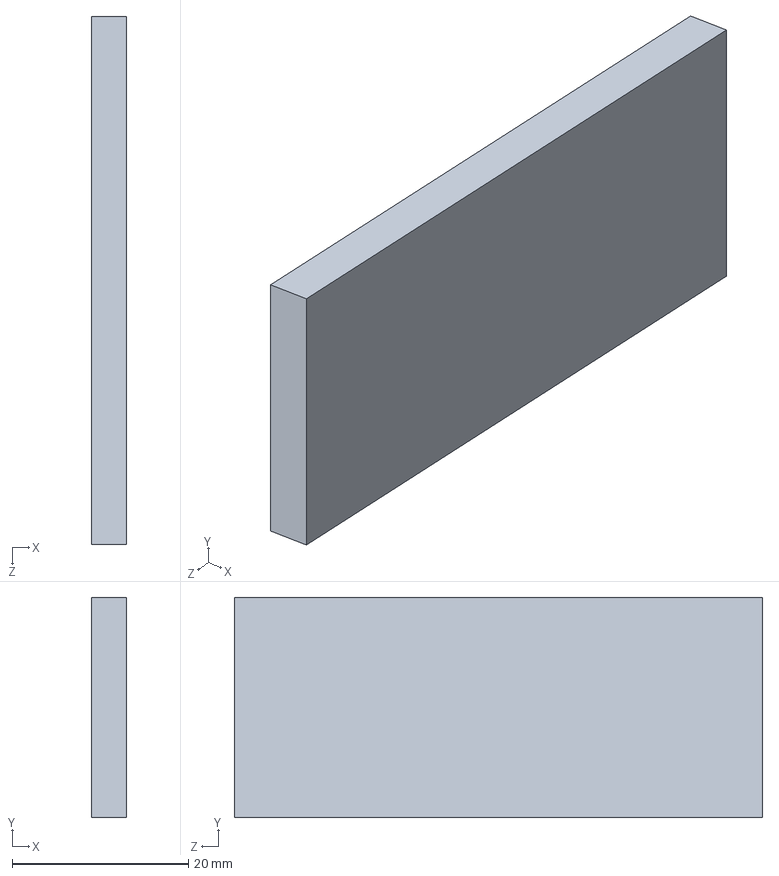
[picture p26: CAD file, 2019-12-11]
Hardware Files/Enclosure Design/FrontSide.SLDPRT
4.00 x 25.0 x 60.0 mm

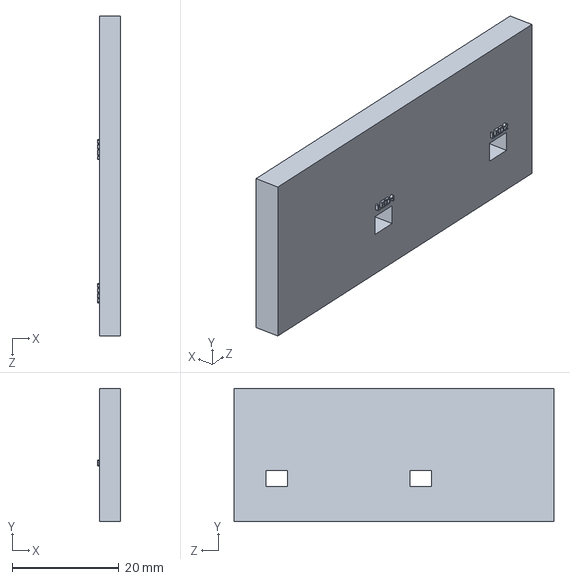
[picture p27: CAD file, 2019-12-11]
Hardware Files/Enclosure Design/BackSide.SLDPRT
4.40 x 25.0 x 60.0 mm

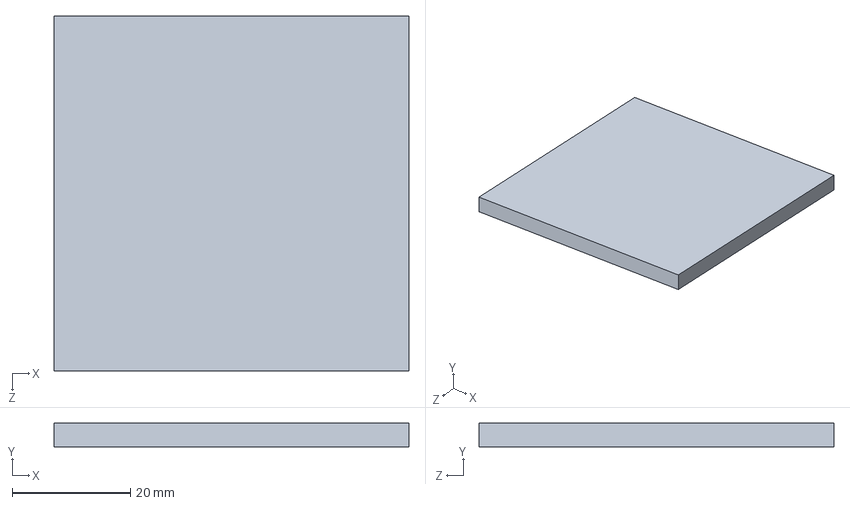
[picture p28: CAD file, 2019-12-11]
Hardware Files/Enclosure Design/Bottom.SLDPRT
60.0 x 4.00 x 60.0 mm

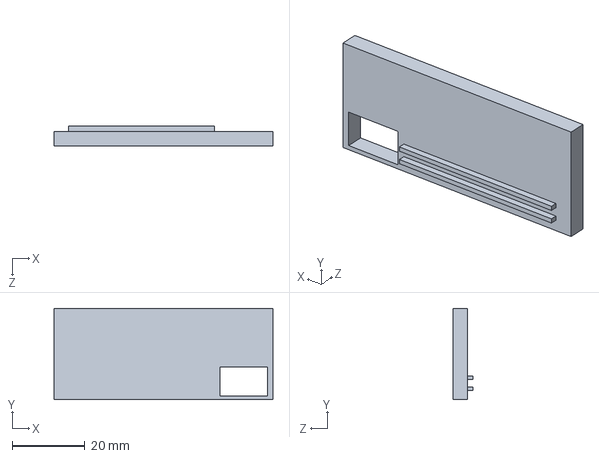
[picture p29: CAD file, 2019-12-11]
Hardware Files/Enclosure Design/LeftSide.SLDPRT
60.0 x 25.0 x 5.50 mm

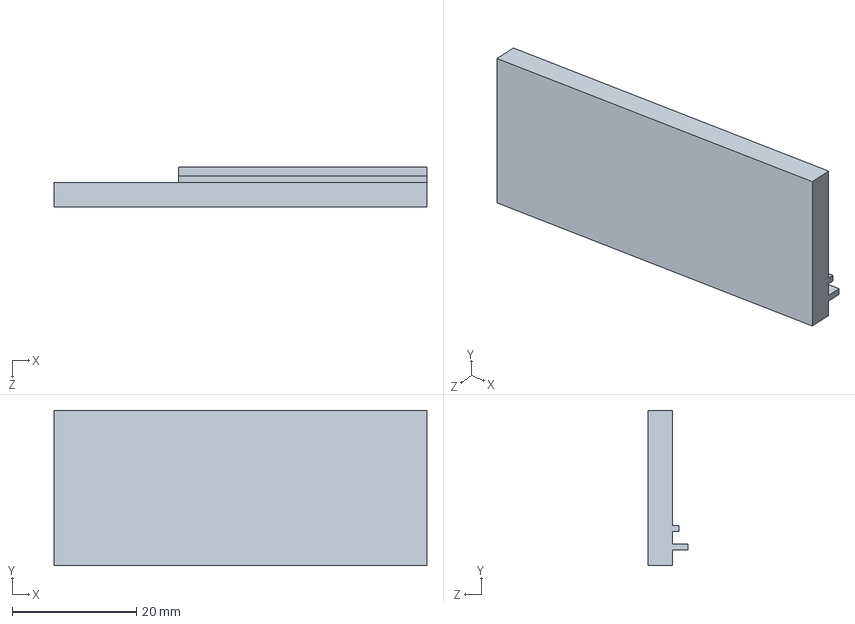
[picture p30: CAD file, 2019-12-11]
Hardware Files/Enclosure Design/RightSide.SLDPRT
60.0 x 25.0 x 6.51 mm

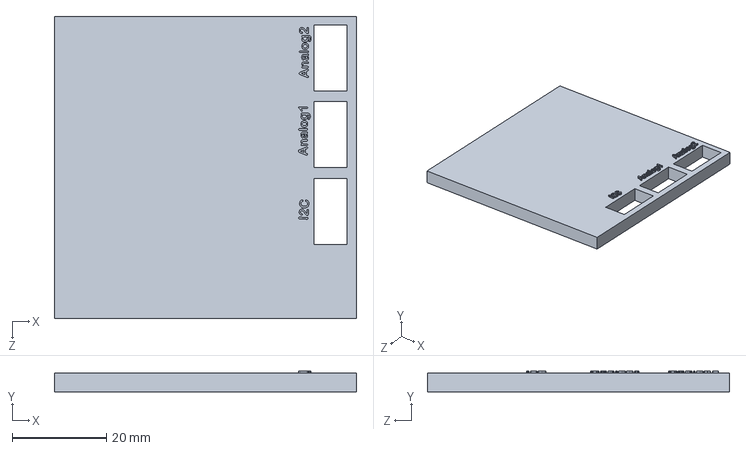
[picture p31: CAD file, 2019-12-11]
Hardware Files/Enclosure Design/Top.SLDPRT
64.0 x 4.40 x 64.0 mm

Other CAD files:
Software Files/Software Examples/Ex4_I2C/Debug/driverlib/MSP430FR5xx_6xx/eusci_b_spi.obj
Software Files/Software Examples/Ex4_I2C/Debug/driverlib/MSP430FR5xx_6xx/mpu.obj
Software Files/Software Examples/Ex4_I2C/Debug/driverlib/MSP430FR5xx_6xx/ram.obj
Software Files/Software Examples/Ex4_I2C/Debug/driverlib/MSP430FR5xx_6xx/saph.obj
Software Files/Software Examples/Ex4_I2C/Debug/driverlib/MSP430FR5xx_6xx/saph_a.obj
Software Files/Software Examples/Ex4_I2C/Debug/driverlib/MSP430FR5xx_6xx/sysctl.obj
Software Files/Software Examples/Ex4_I2C/Debug/driverlib/MSP430FR5xx_6xx/rtc_c.obj
Software Files/Software Examples/Ex4_I2C/Debug/driverlib/MSP430FR5xx_6xx/lcd_c.obj
Software Files/Software Examples/Ex4_I2C/Debug/driverlib/MSP430FR5xx_6xx/mpy32.obj
Software Files/Software Examples/Ex4_I2C/Debug/driverlib/MSP430FR5xx_6xx/dma.obj
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

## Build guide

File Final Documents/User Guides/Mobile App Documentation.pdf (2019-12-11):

# How to Use and Modify the Scout IoT application

This application is available for Android devices only. When you open the application, you will be met with the screen seen below.

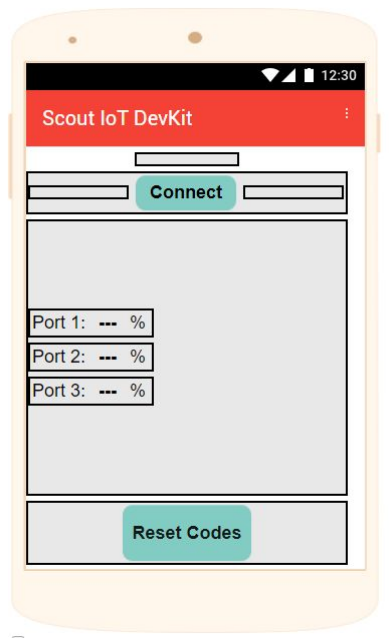
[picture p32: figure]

Select the ‘Search’ button to scan for available Bluetooth devices. To connect to your kit, tap on it. Your kit’s name may be different if you have changed it in the kit’s code. Once your device is connected, you will see this screen and readings from each port of the device.
Set the telemetry code for each port by selecting “Reset Codes”. This code is also set in the ESP32 software. This allows the data to be displayed in the correct port
To disconnect, simply tap the disconnect button.

To view further documentation on Thunkable components, please visit https://classic-docs.thunkable.com/thunkable-classic-android/create/components

More information about the BLE extension is available here: http://iot.appinventor.mit.edu/#/bluetoothle/bluetoothleintro

To view this app in Thunkable and make your own modifications, download the .aia file. Then select the “Apps” tab in Thunkable Classic and select “Upload legacy project from my computer”. To run this app on an Android device, select ‘Export’ and save the .apk file to your Andriod device either via email or Google Drive.

# The Basics of Thunkable

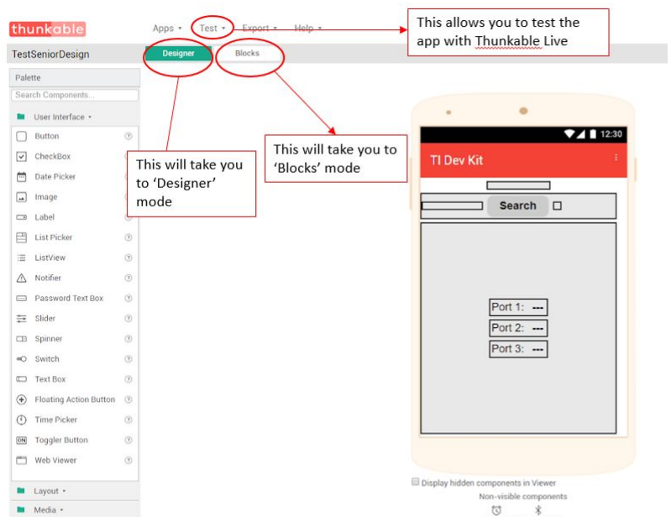
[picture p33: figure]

To modify this app to better suit your project, you can edit the app in Thunkable. The Designer mode allows you to add both visible and invisible components, such as buttons, text, and Bluetooth. Blocks mode allows you to create the logic for each of the components you add.

# Designer Mode

When you open the app in Thunkable, the default mode will be Designer mode. You can see the list of the components that make up the app on the right hand side of the screen. When you select a component, you will be able to edit things like font, size, and color in the ‘Properties’ column. The screen that is set up in designer mode is the opening screen only. If a component is not intended to be visible from the initial screen, you can unselect ‘Visible’ at the bottom of the ‘Properties’ column. Any changes to what is visible as you use the app will be done in ‘Blocks’ mode.

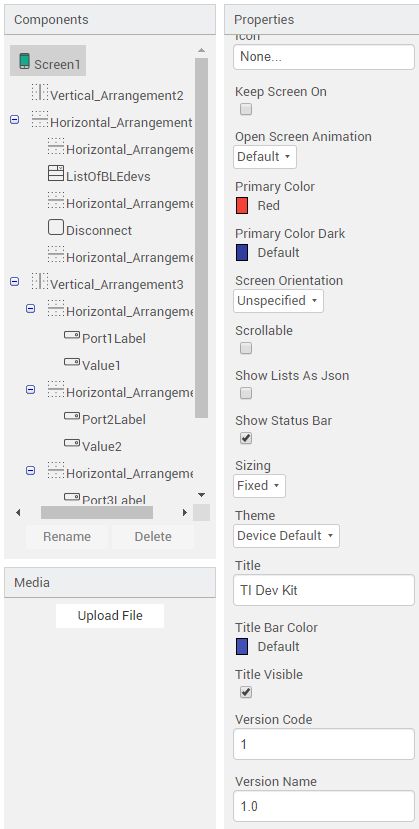
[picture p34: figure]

### Horizontal and Vertical Arrangements

You will see many instances of Horizontal and Vertical Arrangements in the component list. These are blocks that allow you to add things like buttons and text. The components will either show vertically (if Vertical) or horizontally (if Horizontal). To rearrange any component or arrangement, you can click and drag with your mouse.

### List of Devices

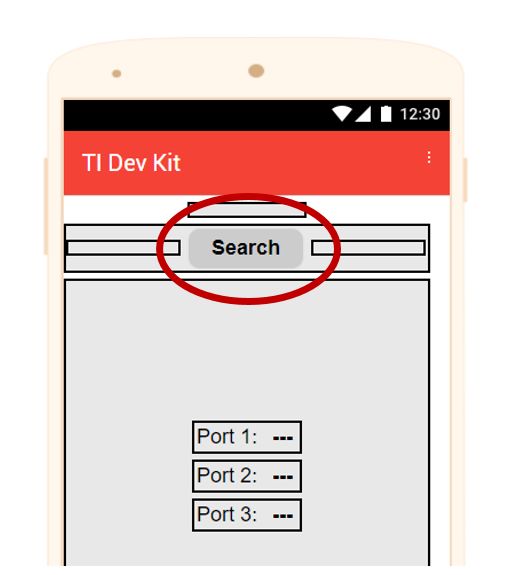
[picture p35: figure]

A List Picker is used to show which devices are available for connection. Initially, it will show a button, in this case the button says ‘Search’. Once pressed, a list will appear, in this case it will list available BLE devices. Once an item is selected, it will disappear.

### Labels

Labels are equivalent to text boxes.

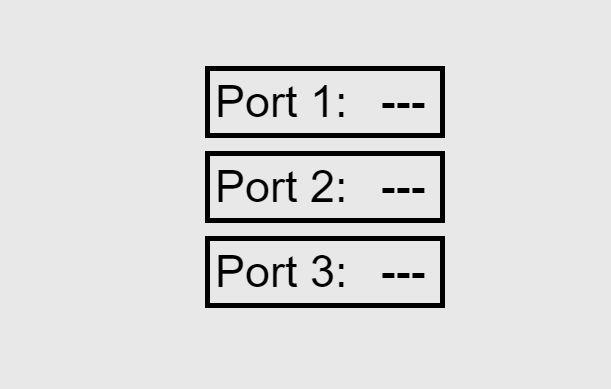
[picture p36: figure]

Here, there are two labels in each horizontal arrangement. One label holds the text “Port #:” and the other will display the value, which is initialized to “---”. The initial value of the label should be written in the ‘Text’ box under properties. If you want the text in the label to change later, which we will do when displaying sensor readings, you must do it in the Blocks mode.

### Non-visible components

Below the phone screen you will see a selection of ‘non-visible’ components. Things that are added here are not visible in the GUI, but will be used in the ‘Blocks’ portion of the app. For this app you will see Bluetooth Low Energy and Clock 1 listed as non visible components. Bluetooth Low Energy is an extension provided by MIT App Inventor, which can be added under ‘Extensions’. To view further documentation for this component please visit http://iot.appinventor.mit.edu/#/bluetoothle/bluetoothleintro

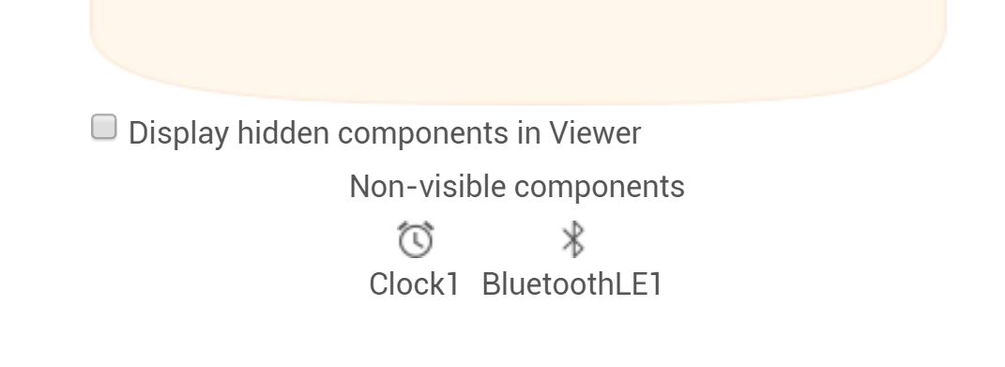
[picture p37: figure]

# Blocks Mode

Blocks mode is used to implement the logic of the app, like what happens when buttons are pressed. When you switch to Blocks mode, the screen will look like this:

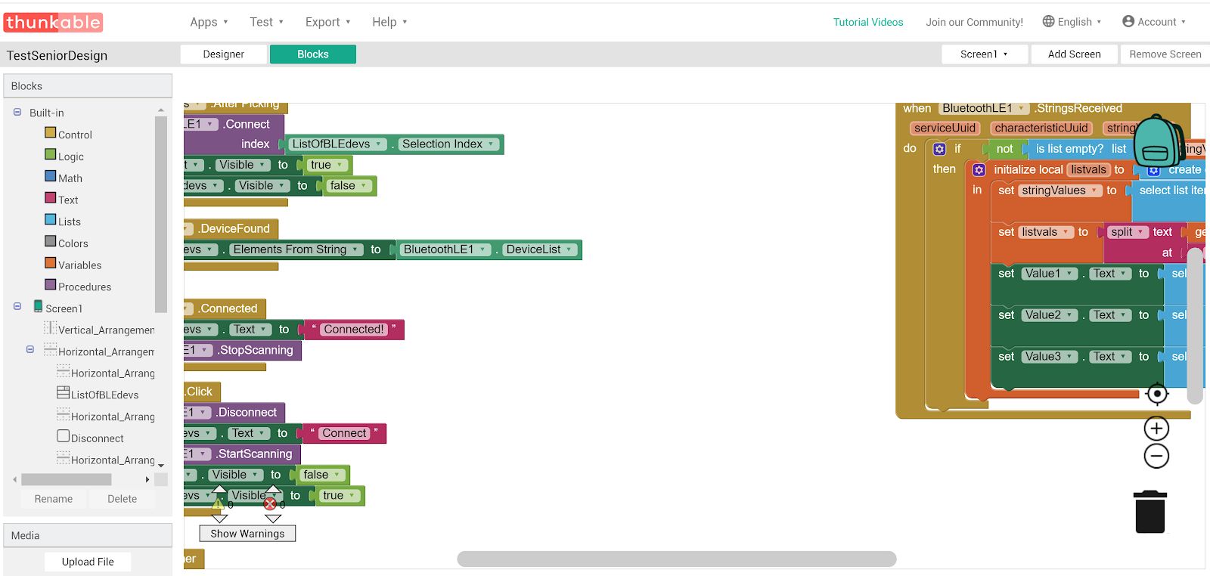
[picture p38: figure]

On the left, you have a selection of different functions. On top are basic logic functions such as ‘if, else’ statements, and variable declarations. On the bottom is a list of the components you’ve added in ‘Designer’ mode, and when you select one you will be given a number of statements relating to that component. Thunkable works by connecting the logic blocks with the component blocks. Below is a description of some of these blocks.

Bluetooth

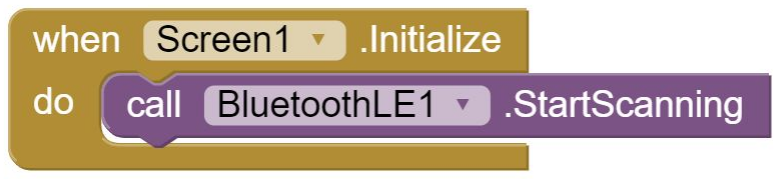
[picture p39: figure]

The purpose of this block is to begin scanning for BLE devices when the app opens. The yellow block’s purpose is to do whatever is nested inside it when screen 1 (the only screen in this app) opens for the first time. The purple block’s purpose is to call the BLE scan function. The yellow block will be found under ‘Screen 1’ and the purple block will be found under ‘BluetoothLE1’, both in the component list.

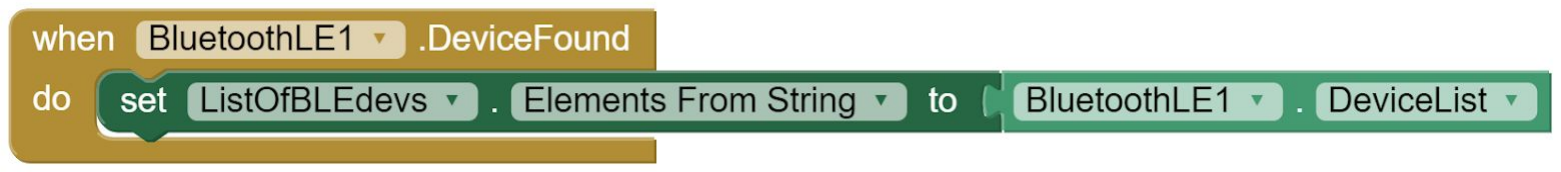
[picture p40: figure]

The purpose of this block is to put any device found by the BLE scan function into the list picker so we can select which device is ours.

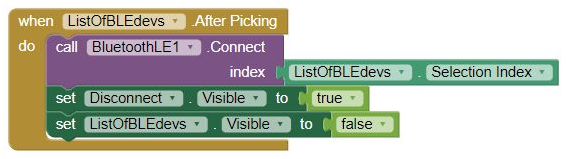
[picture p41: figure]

This block describes what action to take after picking an item from the list picker. When a device is chosen it will connect using BLE, set the disconnect button to visible, then set the list picker to invisible. The ‘true’ and ‘false’ components are found under ‘Logic’ in the top section of components.

This block states what to do when a device is connected. The button on the list picker will now read “Connected!” and the BLE component will stop scanning. The hot pink text box can be found under ‘Text’.

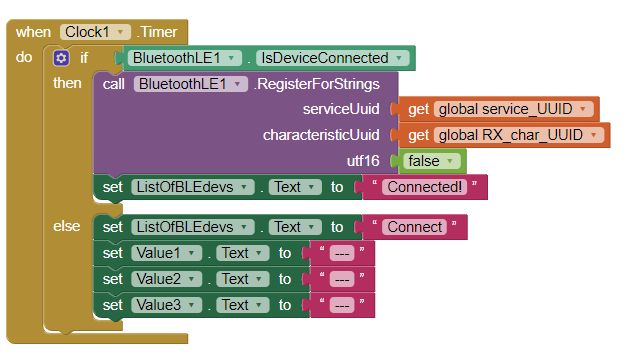
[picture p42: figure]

This block is controlled by a timer. The timer interval can be set in Designer mode. When the timer goes off, this block is executed. If a device is connected, the block will register the device to receive strings, rather than integers or floats. The UUID is the Universally Unique Identifier, the one used in this project is generic. It is set under global variables, which are variables that can be used in any block. Local variables are set in one block and can only be used in that block.

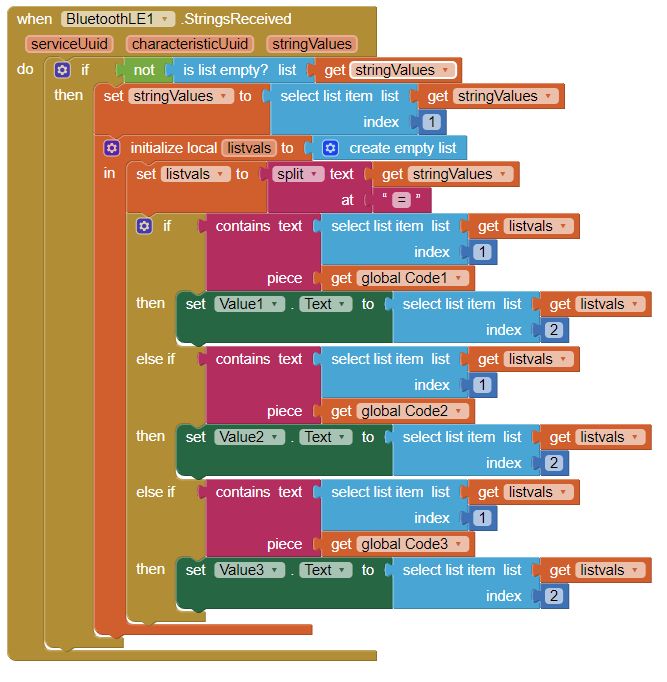
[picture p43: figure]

This block will run every time a BLE string is received. The block provides the variables of the transmit and receive UUID as well as the string value. If the value is not empty, the block will begin parsing the information. The data is sent in the format “light=50” with light being the code word and 50 being its value. A local variable, listvals, is initialized to hold the code word in the string as one list value, and the value as the other list value with the split text function. If this codeword matches one of the user input words, the value label will change its text to match the value in the list.

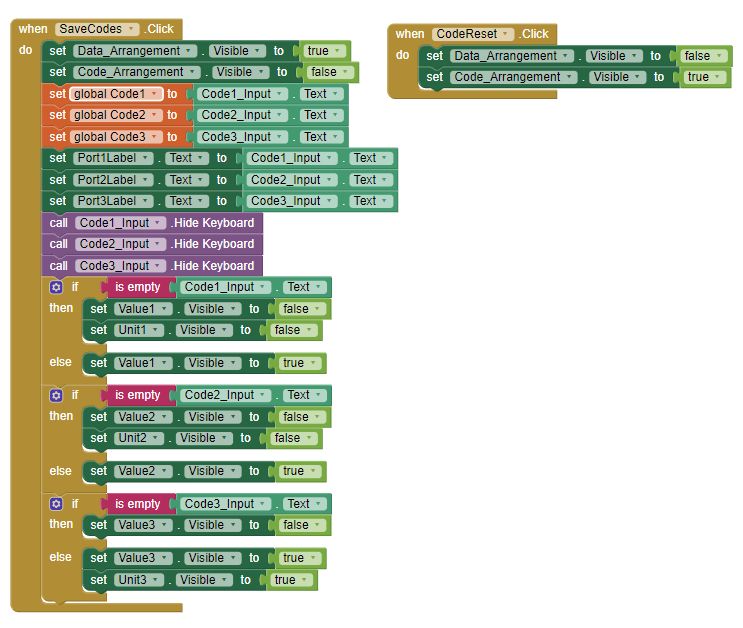
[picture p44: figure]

These blocks set the user input code words. When the code reset button is pressed, the screen arrangement will be set to the text input screen. Here the user will type in the words they want to use and the app will save them to a global variable. If a certain port is not being used, the text for that port will be set to invisible.

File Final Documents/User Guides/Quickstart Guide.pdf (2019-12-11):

# SCOUT

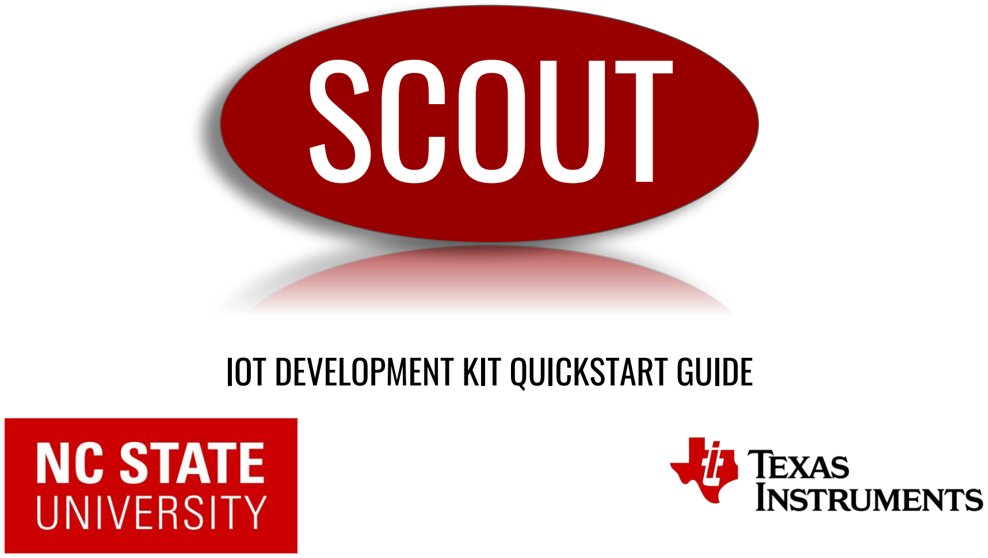
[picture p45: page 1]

# IOT DEVELOPMENT KIT QUICKSTART GUIDE

# Scout IoT Development Kit MSP430FR5994 and ESP32

Flashing software to the MCU
1. Install Code Composer Studio
2. Clone one of the example projects from https://github.com/NCSU-Scout-IoT/SeniorDesignF2019
3. Connect the TCK, TDIO, and GND pins to the same pins on your MSP-EXP430FR5994 LaunchPad and power your board
4. Connect your LaunchPad to your PC
5. Flash the program using Code Composer Studio.

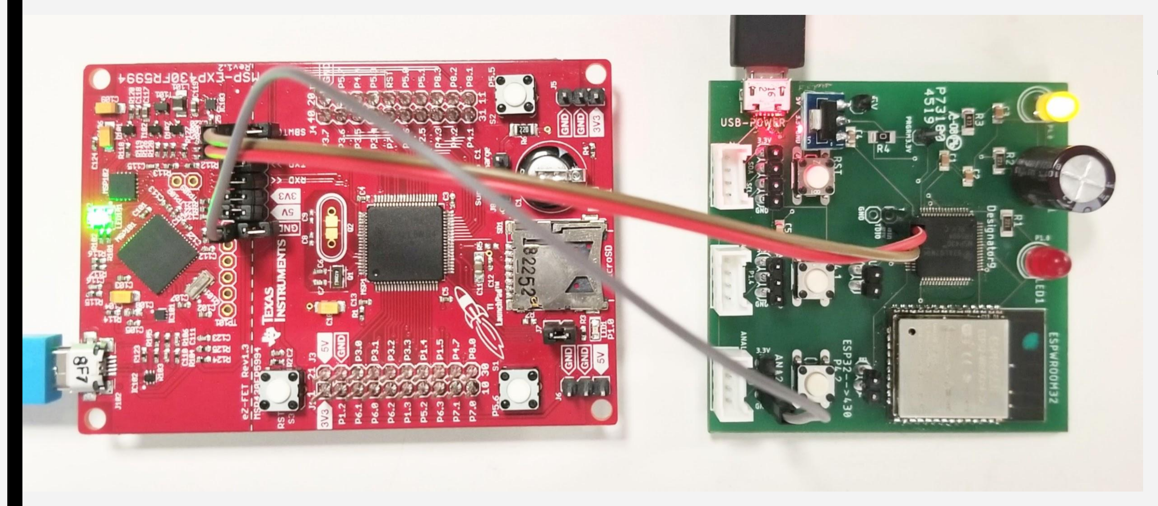
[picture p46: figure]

Out-of-box Examples

Go to [link] for all the out-of-box example projects.

The full IoT example project will take data from an analog sensor, convert it to a percentage and send the data to Microsoft Azure IoT Hub when given an SSID, password, and IoT Hub connection string. For more information about IoT Hub, refer to https://docs.microsoft.com/en-us/azure/iot-hub/about-iot-hub

The IoT field can be intimidating to those with little experience. The Scout is a user-friendly and inexpensive platform for IoT development that is a viable option for users at any experience level. All that is required is a TI Launchpad and Code Composer Studio. The Scout is compatible with SEEED Grove Sensors right out of the box.
Required Hardware:
- MSP-EXP430FR5994 LaunchPad
- PC
- 2 x MicroUSB cables
- Jumper wires
- Sensors

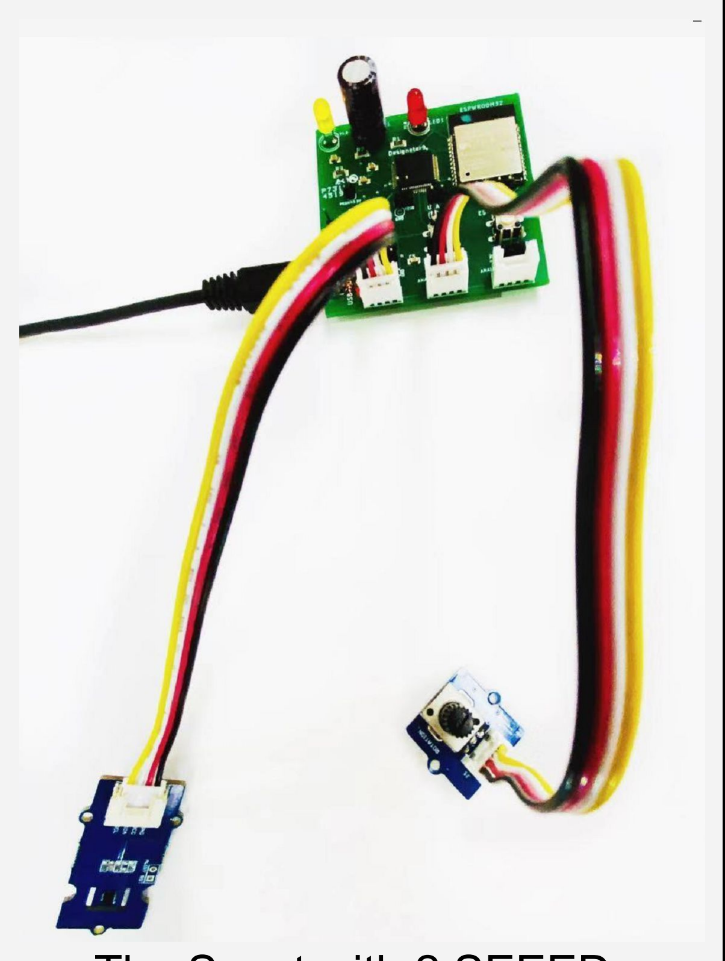
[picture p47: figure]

The Scout with 2 SEEED
Grove Sensors

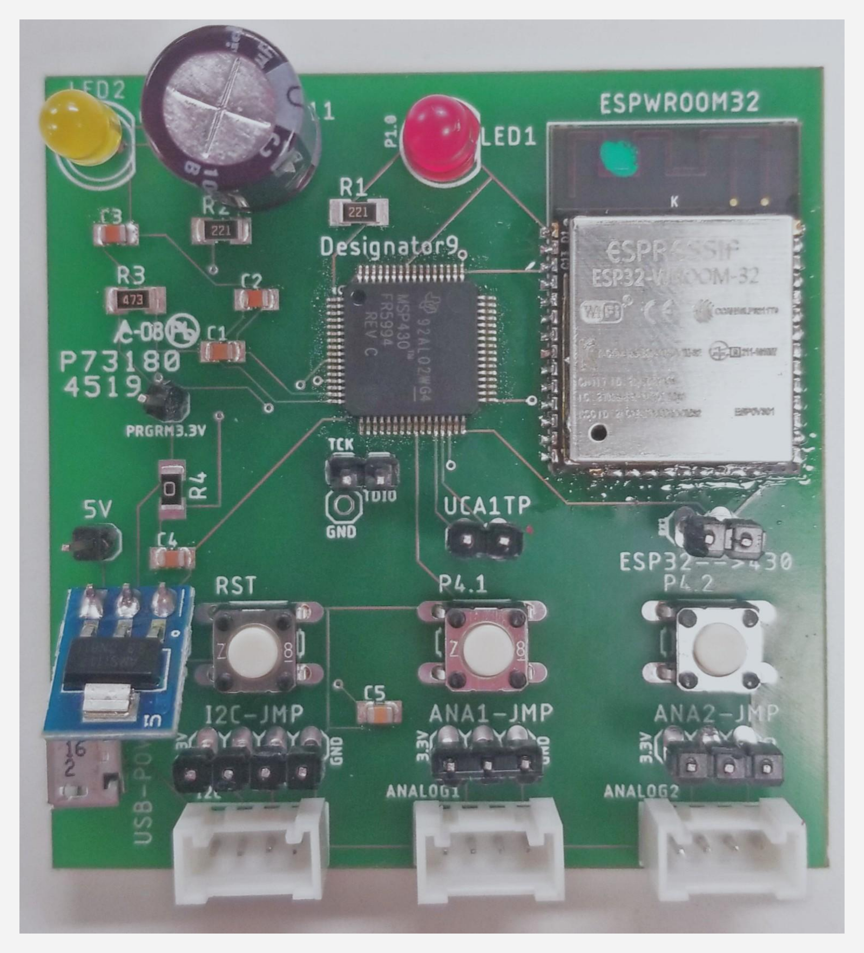
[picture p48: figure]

The Scout IoT DevKit

The Launchpad
connected to the
Scout for
programming

General Layout | Pin Layout

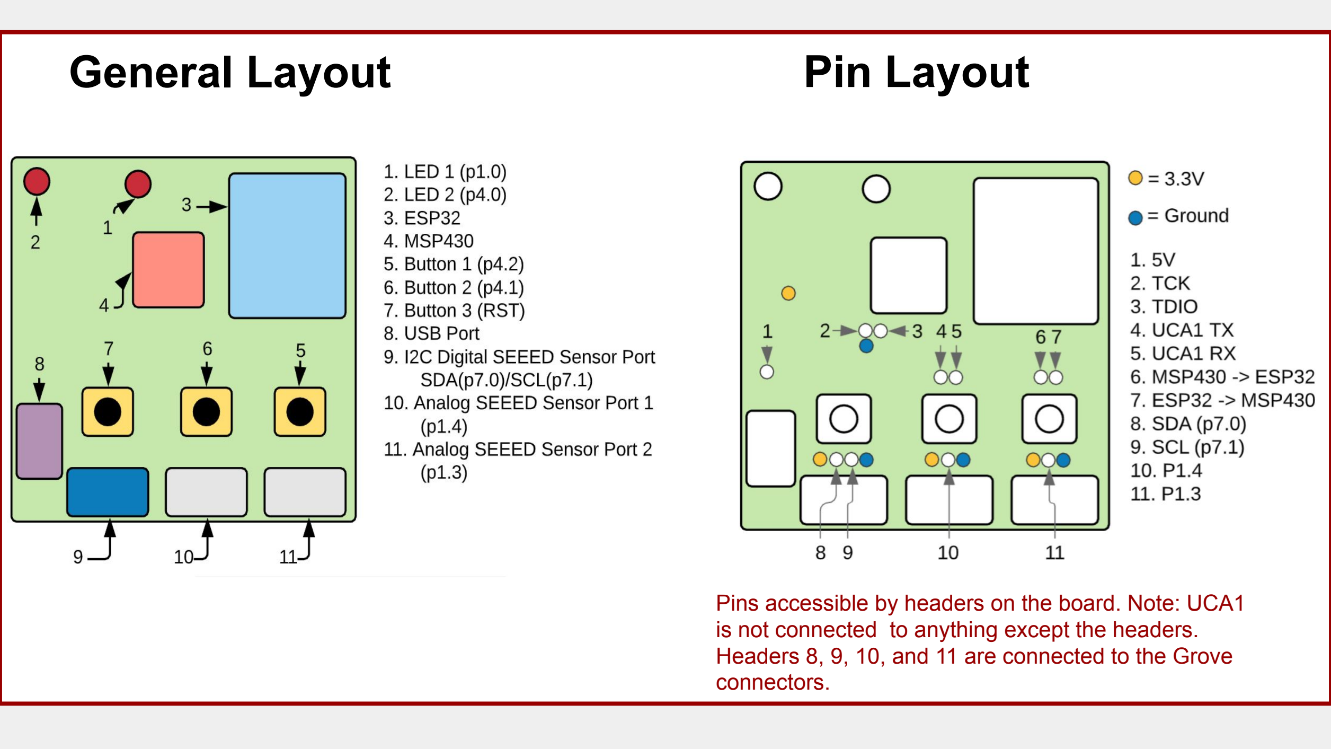
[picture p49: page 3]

Pins accessible by headers on the board. Note: UCA1 is not connected to anything except the headers. Headers 8, 9, 10, and 11 are connected to the Grove connectors.

# Setting Up the Scout For Use With a TI Boosterpack

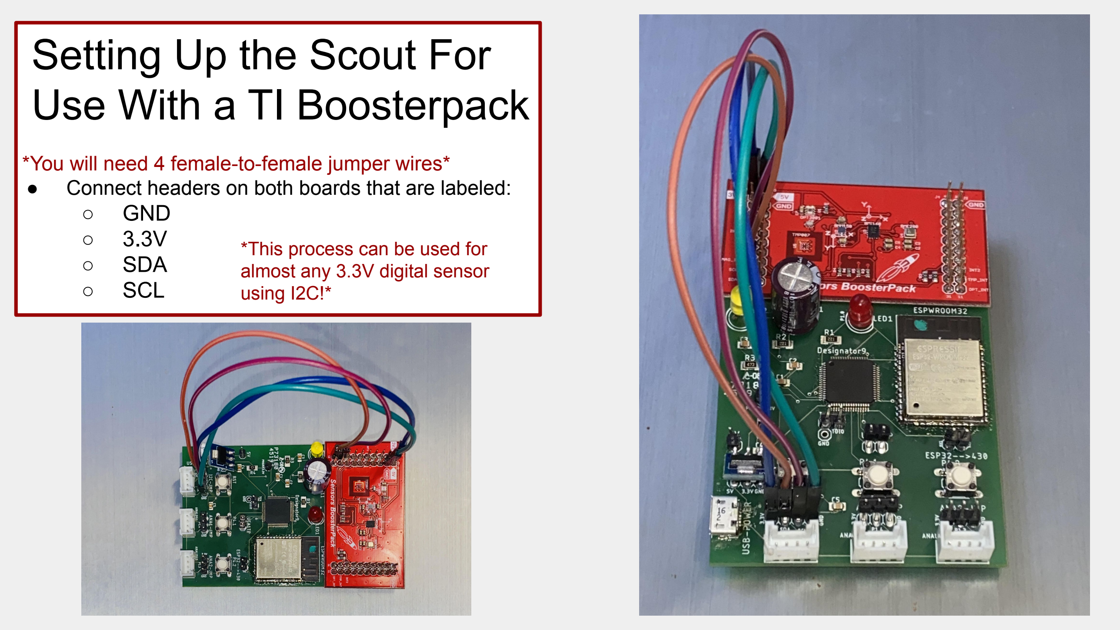
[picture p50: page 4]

### *You will need 4 female-to-female jumper wires* - Connect headers on both boards that are labeled:

## - GND

- 3.3V

## - SDA - SCL

*This process can be used for almost any 3.3V digital sensor using I2C!*

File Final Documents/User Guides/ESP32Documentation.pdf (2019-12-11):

The ESP32 is connected by its U0 port to the UCA0 port on the MSP430. There are two test points that can be used to monitor the communication between the two chips. The ESP32’s default baud rate 115200 baud/sec. The software examples with the ESP32 will all initialize the port and UCA0 to the correct configuration.

All commands must be followed by a carriage return character (‘\r’). If the command is not recognized, the ESP32 will respond with ‘?’. If a command is successfully executed, the ESP32 will respond with ‘OK’ and a linefeed (‘\n’). If there is an error in executed a recognized command, there will be an error message describing the problem.

Command | Usage | Description
ssid | AT+ssid=<ssid> | Sets the SSID of the AP the ESP32 will attempt to connect to when in Wi-Fi mode. If a password is already set, an attempt at connection will begin.
pass | AT+pass=<password> | Sets the password that will be used when attempting to connect to an AP.
connString | AT+connString=<connection string> | Sets the IoT Hub connection string. A connection string is obtained after creating a new device in your IoT Hub.
telemetry | AT+telemetry=<name>,<value> | While in Wi-Fi mode and connected to Internet and IoT Hub, this command will send the appropriate message to Azure with the <name> and <value>. If in Bluetooth mode, this command will send the info to the mobile app if connected.
mode | AT+mode=<0 or 1> | If mode = 0, then the device will be set to Wi-Fi mode, and if the SSID and password are set, will attempt connection. If mode = 1, the device is in Bluetooth mode and will attempt to send info to the app.
baud | AT+baud=<baud rate> | Sets the baud rate to the desired value. Use rates of over 500,000 baud/sec at your own risk. The MSP430 baud rate will need to match this after the command is sent.
sleep | AT+sleep=<time> | Sets the ESP32 into sleep mode for <time> seconds

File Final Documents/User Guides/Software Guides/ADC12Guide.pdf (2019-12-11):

Example 3 – Analog-to-digital Converter

The most popular form of sensor is one that outputs an analog voltage level to represent its data. A light sensor might output 0.01V in darkness and 3.2V in bright light. The analog-todigital converter (ADC) on the MSP430 samples this voltage level, compares it to a reference such as the 3.3V VCC, and converts it to a digital integer that we can use in our programs. This example project samples one of the analog Grove connectors, turns on LED 1 if the voltage if more than half VCC, and converts the 12-bit integer the ADC outputs to a string format that can be sent to the ESP32.

The example starts the same as the other except for an extra inclusion. The standard input/output library is included, in its minimal form. We use this library to convert the integer value we get from the ADC to a string. Next, we set up the ports. P1.0 (LED 1) is used as an output again, and P1.4
is set as its ternary
(third) function. In the
datasheet for the
MSP430FR5994, we

can see that the first peripheral function for P1.4 deals with timer TB0, the second with serial port UCA0, and the third is an analog input.

Next the 12 bit ADC is set up. If you want to find out more about how the ADC is set up, you can look in the driver library files. In summary, we give the ADC an input to sample, a memory to store the value, and reference voltages. We are using port P1.4, which is input A4.

In the main while loop, the delay cycles function is used for delay in place of a timer for simplicity. The conversion is then begun, enabling the interrupt that will trigger when the conversion is completed. A character array is declared to store our string representation of the value. The value is then converted to a string and stored in the buffer we just declared.

Next is the ISR for the ADC. Since many sources can trigger this interrupt, we need to differentiate between them. The different possible sources are commented next to each case in the switch statement, and the case for MEM0, which we selected as our memory output, is where our code is. We save the contents of MEM0 to a global integer variable so that we can access it in the main loop. If the value is greater than 0x7FF which is half the maximum 12-bit value 2¹² -1
= 4095, then LED 1 is turned on, otherwise it is turned off.

The last part of the code is the function that will convert the sampled integer to a string (an array of characters terminated will a null character 0x0). The first step is converting the 16-bit value to a 32-bit value. An unsigned 16-bit integer has a maximum value of 65535 (2¹⁶
-1),
but to get an accurate calculation, we may need to use numbers greater than this maximum, so we need more bits. We then multiply by 100,000 so that it can be divided by 4096. Remember in integer division, the remainder is not considered, so the larger our value is, the more accurate this calculation will be.

Example:

value = 3,100

In normal arithmetic:
3,100
4,096

× 100 = 75.6836%

However, in integer arithmetic, 3100/4096 = 0. If we do the multiplication by 100 first, in integer arithmetic:

3,100 × 100 = 31,000

31,0000
4,096 = 75

Which is OK, but not as accurate as we might like. To get a more accurate answer, we can multiply by a larger number first:

3,100 × 100,000 = 310,000,000

310,000,000
4,096 = 75,683

This result is much closer! Let’s say we only want two decimal places, but want to keep the precision of a large pre-multiplier. After the division with 4096, we can divide by 10 to get 7,568. Now to get 7,568 to a string we can use the sprintf function from stdio.h. This will give us in our buffer:

This is not exactly correct, of course. We need to add a decimal point, and since we know our value will always have two digits after the decimal point, it is fairly simple to add. The last part of the function adds leading zeros if necessary2, then adds the decimal point.

‘7’ | ‘5’ | ‘6’ | ‘8’ | 0x0

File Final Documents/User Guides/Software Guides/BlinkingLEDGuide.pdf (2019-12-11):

Example 1: BlinkingLED

The first example is very simple, but it will show the basics of GPIO (General Purpose Input/Output) pins and interrupt routines. The first step is to get set up in Code Composer Studio. Then, import this example project from the Github directory: https://github.com/NCSU-Scout-IoT/SeniorDesignF2019. (https://github.com/NCSU-Scout-IoT/SeniorDesignF2019) After you have the project in CCS, try connecting your Scout to your LaunchPad and flashing the example to your board.

The first thing you will see is a short comment block with an explanation of what is happening in the example. In the blinking LED example, a timer is set up to operate in compare mode. In the MSP430, a timer is essentially a
counter, and will
increment every time its
clock source ticks. When
in compare mode, every
time it increments, it
compares its value with
the value in a register
called a capture/compare
register (CCR). The
number of CCRs to
choose from depends on
the timer. See the
MSP430FR5994
datasheet for a complete

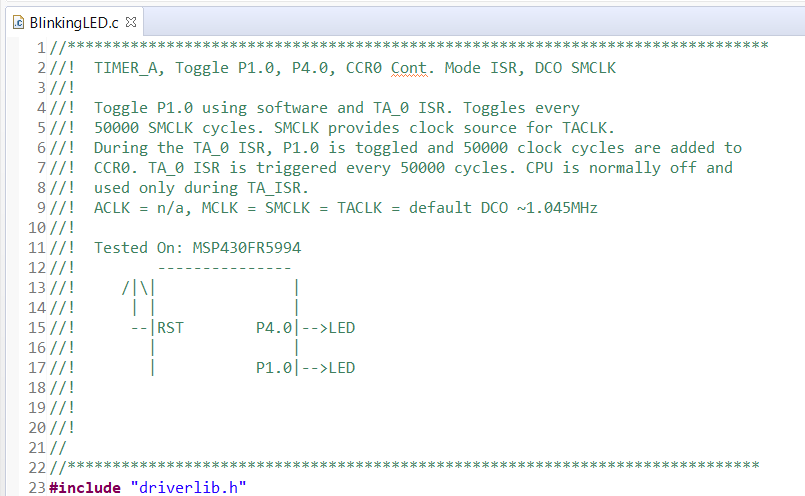
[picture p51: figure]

list of CCRs and timers. For this example, we will use timer TA1 with its first capture/compare register, CCR0. When the timer value is equal to the value in CCR0, the interrupt routine will be called. This is a special function that is accessed in our code no matter where we are when the interrupt is triggered. In this example, however, there is no other code, so the interrupt routine will only wake up from low-power mode. We will look at how exactly this interrupt operates later on.

The first line of code in every example will be the inclusion of the driver library. This library allows us to use functions that will manipulate the internal registers and controls of the MSP430 easily. The second line is the compare value definition. This acts as the period of our timer, the lower it is, the more rapidly the LEDs will blink. It will act as an unsigned 16-bit integer, so its maximum value is 65535. Values above the maximum might give unexpected behavior.

After these two
lines is the beginning of
the main function. The
MSP430 will always begin
operation executing the
main function. The first
line in the main function
stops the watchdog timer.

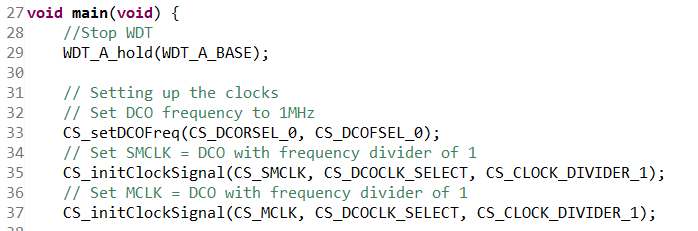
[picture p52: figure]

We will not be using the watchdog timer in any examples. Next, the clocks are set up. This step is optional in this example because the clocks are all at their default frequencies. However, this is a good place to learn a bit about the driver library. If you select one of the arguments to the functions and right click, you can select “Open Declaration” or press F3 to navigate to the location in the driver library where the macro is defined.

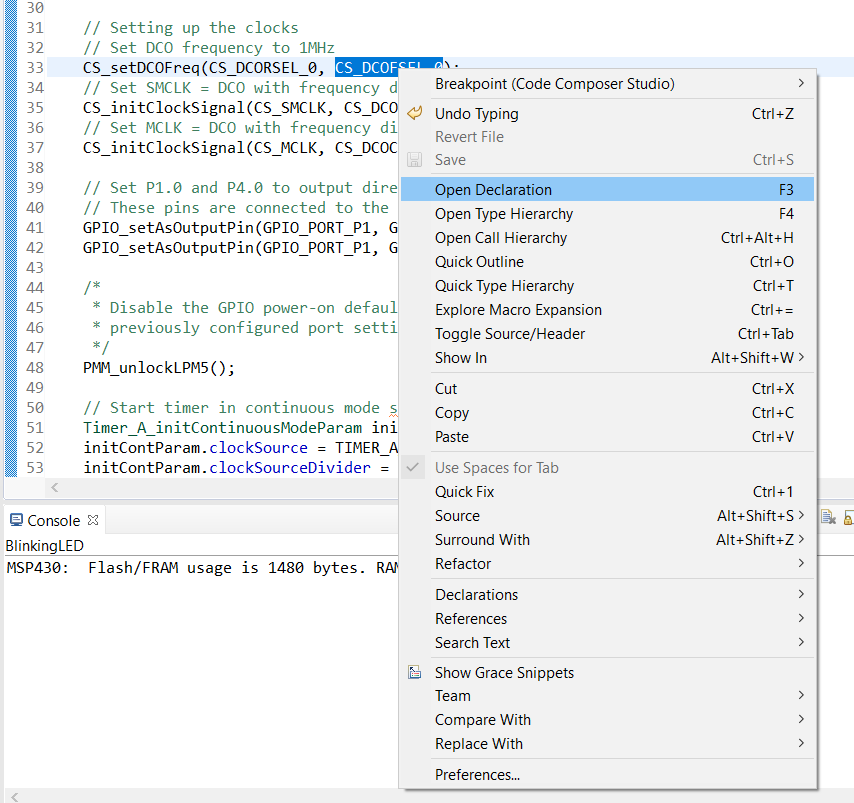
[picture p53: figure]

If you follow this all the way, you will find that CS_DCOFSEL_0 is defined as 0x0000 and you can read in the comments that this translates to a frequency of 1MHz. You can change this macro in your code to one of the others defined and see what happens to your board when you re-flash it. If you ever come across a macro or function you don’t understand or recognize, try following it to the driver library. After all the MCLK (master clock) and SMCLK (sub-master clock) are set to 1MHz, the GPIO pins are then set up.

To set up the ports we need to control the LEDs, we will again use functions from the driver library. You can follow these functions to GPIO.h and see what other options we have when setting up a port and refer to the datasheet to the capabilities of any given port. Keep in mind that the Scout uses the 64-pin PM package, so not every port in the datasheet is available. The two ports connected to the LEDs are set as simple outputs.

Lines 51-72 set up and start the timer. To start the timer, it first needs to be set up in continuous mode, meaning it simply counts up and resets at 2¹⁶
-1. The function to start the timer is line 57, and the function needs an address to specify which timer to start and a struct with all the properties. You can look at all these properties and their valid values in timer_a.h. We set its clock source to the SMCLK with a divider of 8 which translates to a frequency of about 125kHz. We then set the timer to compare mode and point it to CCR0, giving it its initial value on line 69. After the timers are set up and started, the main function ends with putting the MSP430 into low-power mode.

The last part of the example is the interrupt service routine (ISR). The ISR is a function that takes no argument and returns no value and is
always preceded by #pragma
vector=<VECTOR> and
__interrupt. This tells the compiler

that this is the ISR that is triggered by the timer A1. This ISR will toggle the LED on P1.0 every time it is called (line 95) and the LED on P4.0 every other time (line 99) by toggling a boolean true and false. Also in the ISR is some math to calculate what the next value of CCR0 should be. For example if your desired period was 1000, the timer would count to 1000, and your interrupt would trigger. If you did not change CCR0, it would stay as 1000, and your timer would count all the way to 2¹⁶
-1 (65535) before reseting to 0 and then starting over. If you wanted a period of 1000, you would need to add 1000 to CCR0 every time you interrupt, so CCR0 would be 1000, then 2000, then 3000, …and so on. Line 91 calculates the next value of CCR0, and line 104 sets it.

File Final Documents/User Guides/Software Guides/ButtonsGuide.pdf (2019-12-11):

Example 2 – Button Input Capture
The second example builds upon the first, replacing a timer with more advanced GPIO in the form of buttons S1 and S2. We used GPIO in example 1 to toggle the LEDs on and off, and will do the same in this example, but we will also use the GPIO functions to set up the ports connected to the buttons as inputs that trigger interrupts. In the interrupt service routine (ISR), the LEDs will be toggled, depending on which button is pressed.
This example once again begins with a comment block explaining the example and the inclusion of the driver library. We skip setting up the clocks unlike the previous example, so the MSP430 will run at its default 1MHz. The GPIO is set up starting on line 38. Ports P1.0 and P4.0 are set as outputs for the LEDs as before. Ports P5.5 and P5.6 are set as inputs with internal pull-up resistors. As you can see from the schematic, the buttons are switches to ground, so in order to get a good high-to-low transition that the MSP430 can recognize, a pull-up resistor is required. On line 44, the interrupt edge is selected. When the buttons are not being pressed, they are connected to 3.3V via the internal pull-up resistor, and when the buttons are pressed, they are connected to ground. So, if we want to trigger an interrupt when the button is pressed, we need to select the high-to-low edge as our interrupt source.
After the ports are set up, we clear the interrupt flags so that when we enable interrupts, we don’t get any phantom interrupts. Then the MSP430 is set to low-power mode 4 and interrupts are enabled. Notice the power level is much lower than in previous examples as no clocks are needed for a timer.
The last part of code is the interrupt service routine (ISR). Again, this code is only run when an interrupt is triggered.
The only major
difference between this
ISR and the ISR in
example 1 is that this
ISR can be triggered
by multiple sources,
i.e. either button. To
differentiate between

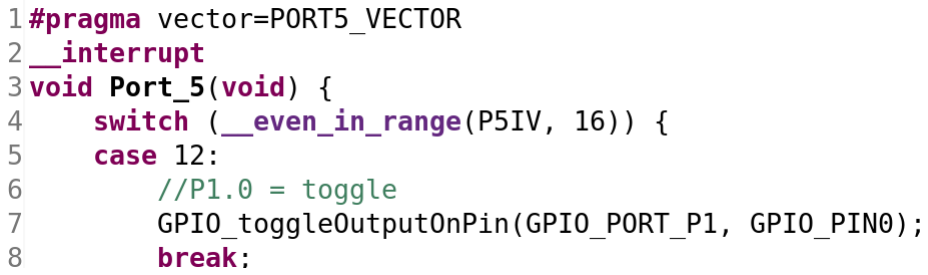
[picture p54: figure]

sources, a switch statement is used on the P5IV register, which contains the source of the interrupt. The LEDs act as a sort of two-bit counter from 00 (both off) to 11 (both on) in binary. One button increments the counter and the other resets it to 00 (both LEDs off).

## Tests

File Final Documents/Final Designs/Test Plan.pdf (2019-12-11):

Power Supply Test Cases | Expected Output | Results | Notes
Check output voltage and current for power supply with Vin = 5V | 3.3 V and 600 mA | Passed
Check output voltage in full system for Vin = 5V | 3.3V and 600 mA | Passed
Successfully provide external power to pcb | ESP32 program runs, MSP430 can be flashed | Passed

Extended Run Test Cases

Run system with sensors on for 24 hours | No interruptions | Passed
Run ESP32 subsystem for 24 hours | No interruptions | Passed
PCB Test Cases | Expected Output | Results | Notes
MSP430 flash test | MSP430 can be flashed using LaunchPad | Passed | Requires external power due to USB port power constraints
Buttons test | LEDs activate when button is pressed | Passed
LED test | LED activate when MSP430 port is active | Passed | Replaced bad LED, passed
Sensor test | Seeed sensors give same values on PCB as BoosterPack | Passed

Software Test Cases | Expected Output | Results | Notes
Pairing button software example | Pairing button functions properly | Passed
Sensor Software Test | Sensor data output to webpage | Passed
App sends data to Azure correctly | Data is received by Azure at the correct port, time, and telemetry | Passed
App receives accurate sensor data | App shows data that is accurate currently and is continuously updated | Passed
App receives data in correct port | Data for each sensor is shown in the corresponding port and is not ever in a separate port | Passed

Command Test Cases

Able to set SSID at runtime | Connects to WiFi properly | Passed
Able to set connection string at runtime | Connects to Azure | Passed
Wifi telemetry command works | Send data to Azure when in Wifi mode | Passed
Bluetooth telemetry command works | Send data to app when in BLE mode | Passed

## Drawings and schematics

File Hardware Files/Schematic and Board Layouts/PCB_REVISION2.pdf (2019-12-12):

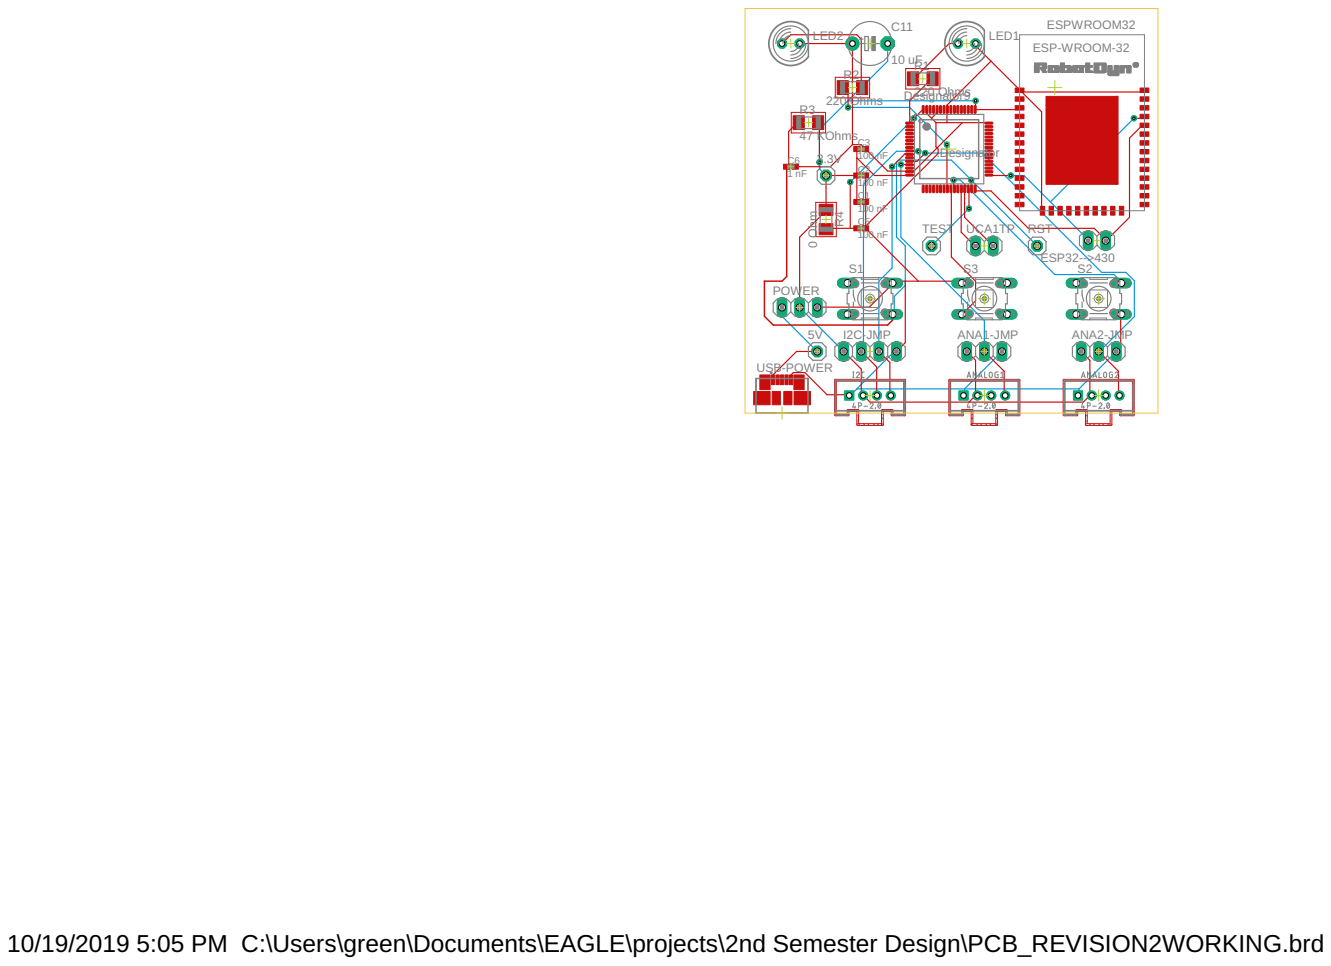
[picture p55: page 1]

10/19/2019 5:05 PM C:\Users\green\Documents\EAGLE\projects\2nd Semester Design\PCB_REVISION2WORKING.brd

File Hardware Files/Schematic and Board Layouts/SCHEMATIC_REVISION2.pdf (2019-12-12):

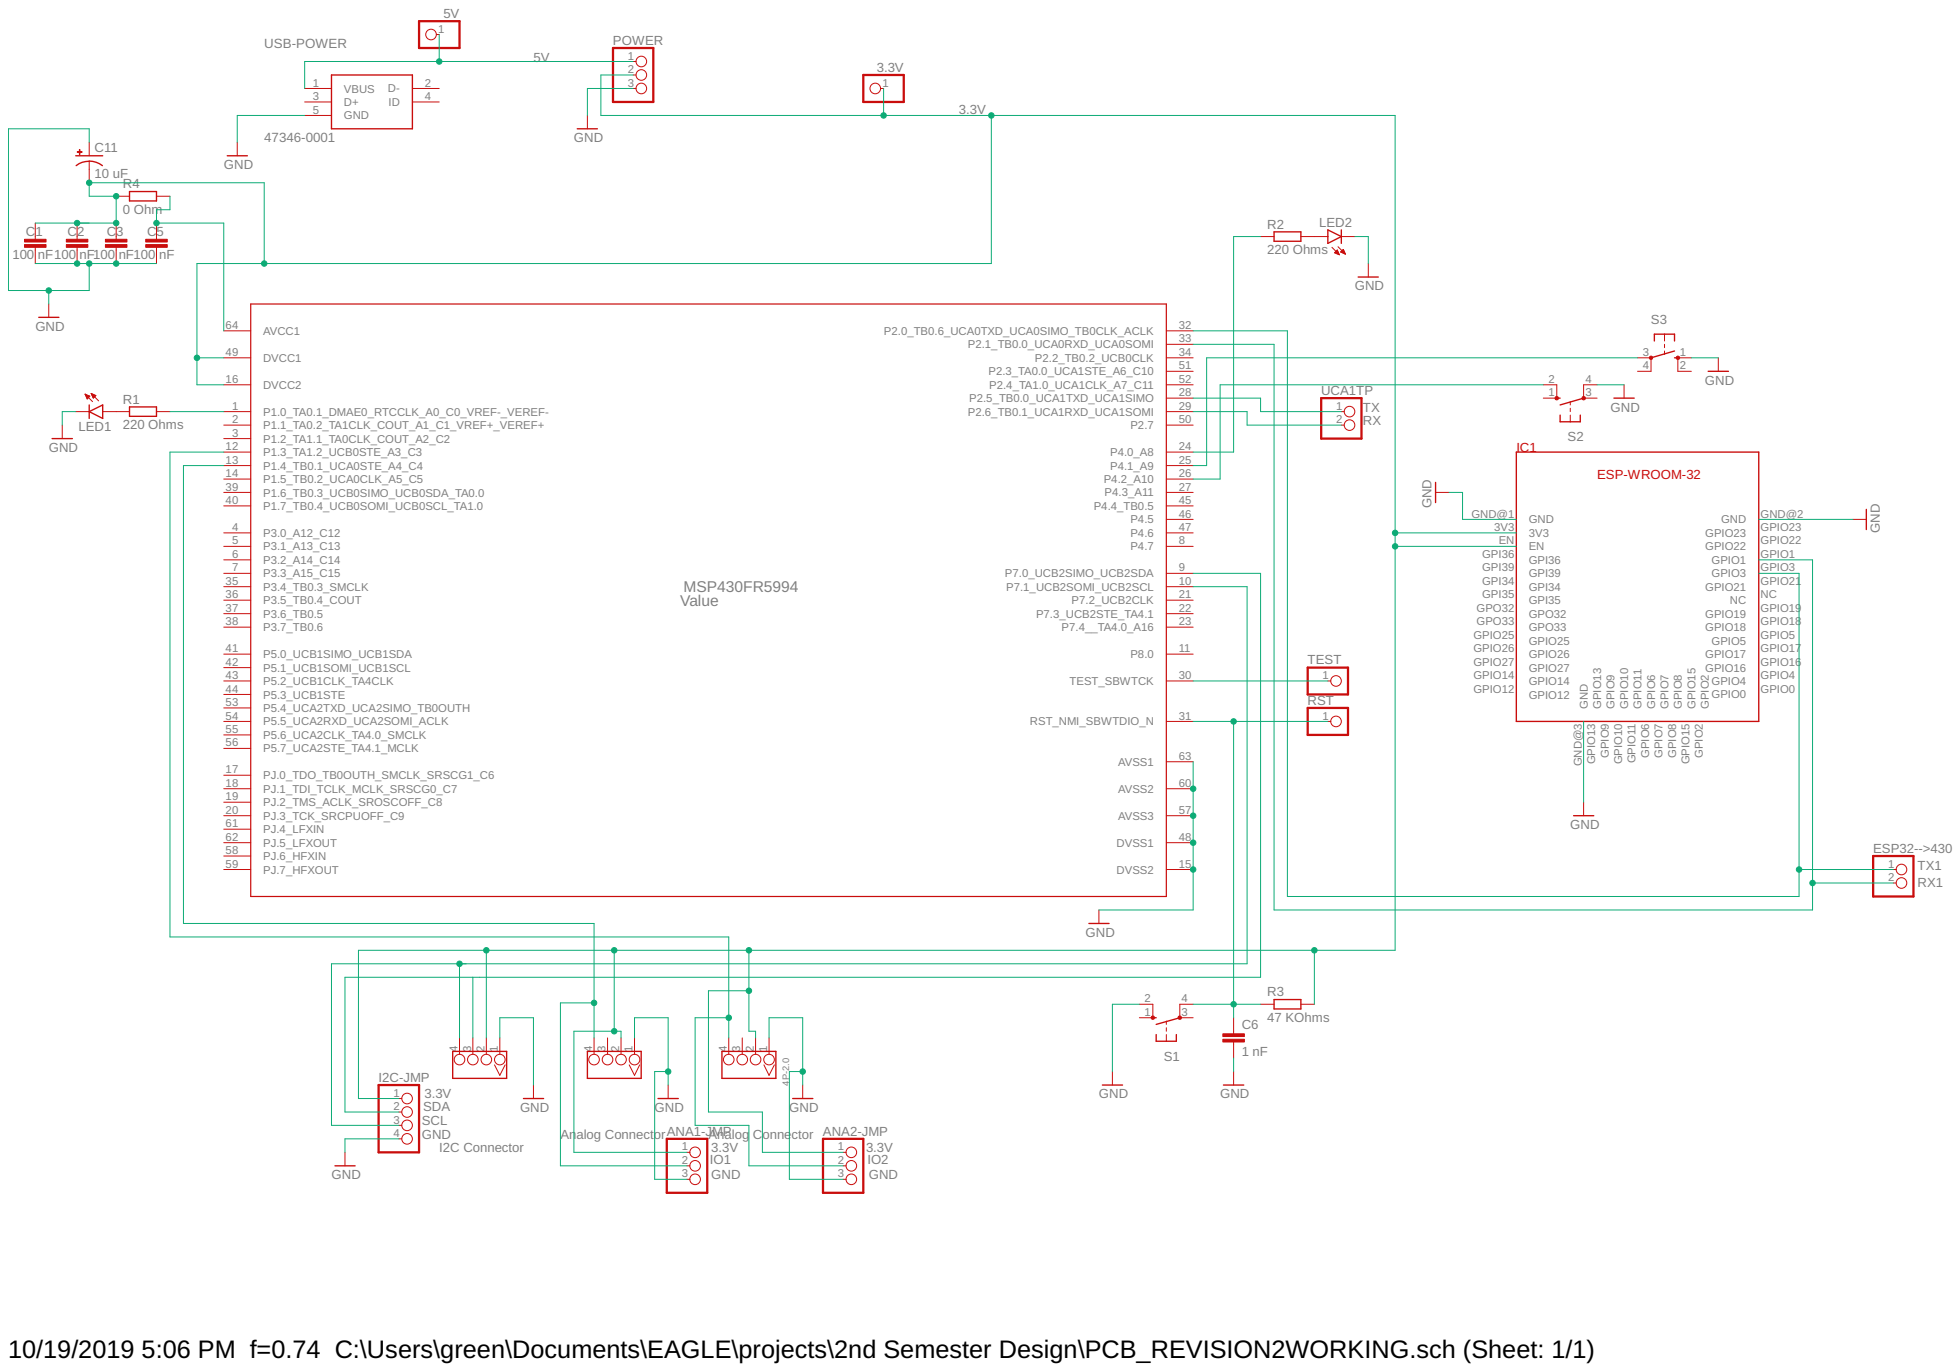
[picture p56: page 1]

32 P2.1_TB0.0_UCA0RXD_UCA0SOMI 33 P2.2_TB0.2_UCB0CLK

16 | 51 P2.4_TA1.0_UCA1CLK_A7_C11

10/19/2019 5:06 PM f=0.74 C:\Users\green\Documents\EAGLE\projects\2nd Semester Design\PCB_REVISION2WORKING.sch (Sheet: 1/1)

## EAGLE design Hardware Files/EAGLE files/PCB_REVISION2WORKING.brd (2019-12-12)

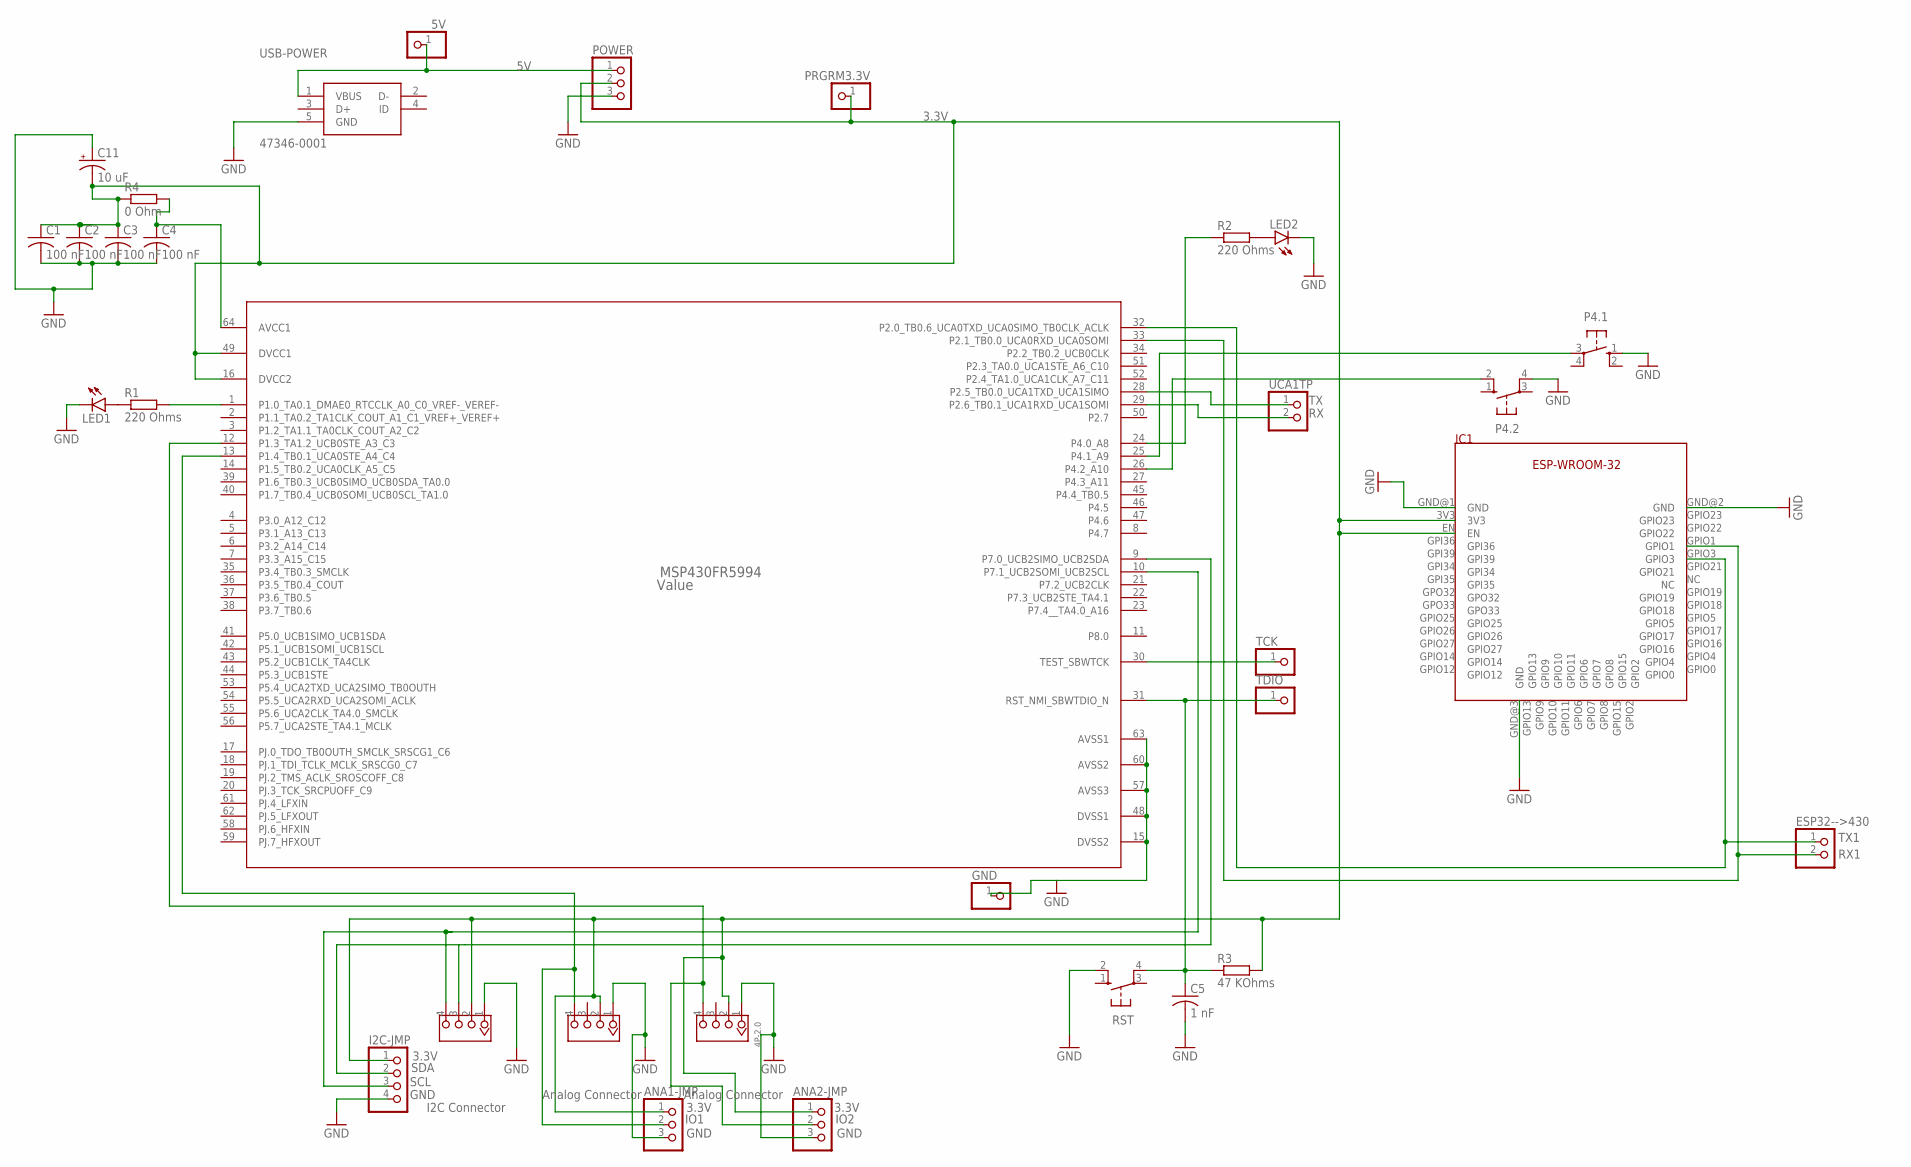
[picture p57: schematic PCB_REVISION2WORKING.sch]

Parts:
5V: PINHD-1X1; 1X01
ANA1-JMP, ANA2-JMP: PINHD-1X3; 1X03
ANALOG1, ANALOG2: 4P-2.0; HW4-2.0
C1, C2, C3, C4: 100 nF; C0805K
C5: 1 nF; C0805K
C11: 10 uF; E5-6
ESP32-->430: PINHD-1X2; 1X02
GND: PINHD-1X1; 1X01
I2C: 4P-2.0; HW4-2.0
I2C-JMP: PINHD-1X4; 1X04
IC1: ESPWROOM32
LED1, LED2: LED5MM
MSP430FR5994: Value; PM0064A_N
P4.1, P4.2: 10-XX; B3F-10XX
POWER: PINHD-1X3; 1X03
PRGRM3.3V: PINHD-1X1; 1X01
R1, R2: 220 Ohms; M1206
R3: 47 KOhms; M1206
R4: 0 Ohm; M1206
RST: 10-XX; B3F-10XX
TCK: PINHD-1X1; 1X01
TDIO: PINHD-1X1; 1X01
UCA1TP: PINHD-1X2; 1X02
USB-POWER: 47346-0001

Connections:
3.3V: ANA1-JMP.1, ANA2-JMP.1, ANALOG1.2, ANALOG2.2, C1.1, C2.1, C3.1, C11.-, I2C.2, I2C-JMP.1, IC1.3V3, IC1.EN, MSP430FR5994.16 (DVCC2), MSP430FR5994.49 (DVCC1), POWER.2, PRGRM3.3V.1, R3.2, R4.1
5V: 5V.1, POWER.1, USB-POWER.1 (VBUS)
GND: ANA1-JMP.3, ANA2-JMP.3, ANALOG1.1, ANALOG2.1, C1.2, C2.2, C3.2, C4.2, C5.2, C11.+, GND.1, I2C.1, I2C-JMP.4, IC1.GND@1 (GND), IC1.GND@2 (GND), IC1.GND@3 (GND), LED1.K (C), LED2.K (C), MSP430FR5994.15 (DVSS2), MSP430FR5994.48 (DVSS1), MSP430FR5994.57 (AVSS3), MSP430FR5994.60 (AVSS2), MSP430FR5994.63 (AVSS1), P4.1.1 (S), P4.2.4 (P1), POWER.3, RST.2 (S1), USB-POWER.5 (GND)
IO1: ANA1-JMP.2, ANALOG1.4, MSP430FR5994.13 (P1.4_TB0.1_UCA0STE_A4_C4)
IO2: ANA2-JMP.2, ANALOG2.4, MSP430FR5994.12 (P1.3_TA1.2_UCB0STE_A3_C3)
unnamed: LED1.A, R1.1
unnamed: LED2.A, R2.2
unnamed: MSP430FR5994.1 (P1.0_TA0.1_DMAE0_RTCCLK_A0_C0_VREF-_VER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), R1.2
unnamed: C5.1, MSP430FR5994.31 (RST_NMI_SBWTDIO_N), R3.1, RST.4 (P1), TDIO.1
unnamed: MSP430FR5994.25 (P4.1_A9), P4.1.3
unnamed: MSP430FR5994.26 (P4.2_A10), P4.2.2 (S1)
unnamed: MSP430FR5994.24 (P4.0_A8), R2.1
unnamed: C4.1, MSP430FR5994.64 (AVCC1), R4.2
unnamed: MSP430FR5994.30 (TEST_SBWTCK), TCK.1
RX: MSP430FR5994.29 (P2.6_TB0.1_UCA1RXD_UCA1SOMI), UCA1TP.2
RX1: ESP32-->430.2, IC1.GPIO1, MSP430FR5994.33 (P2.1_TB0.0_UCA0RXD_UCA0SOMI)
SCL: I2C.4, I2C-JMP.3, MSP430FR5994.10 (P7.1_UCB2SOMI_UCB2SCL)
SDA: I2C.3, I2C-JMP.2, MSP430FR5994.9 (P7.0_UCB2SIMO_UCB2SDA)
TX: MSP430FR5994.28 (P2.5_TB0.0_UCA1TXD_UCA1SIMO), UCA1TP.1
TX1: ESP32-->430.1, IC1.GPIO3, MSP430FR5994.32 (P2.0_TB0.6_UCA0TXD_UCA0SIMO_TB0CLK_ACLK)

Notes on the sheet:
I2C Connector
Analog Connector

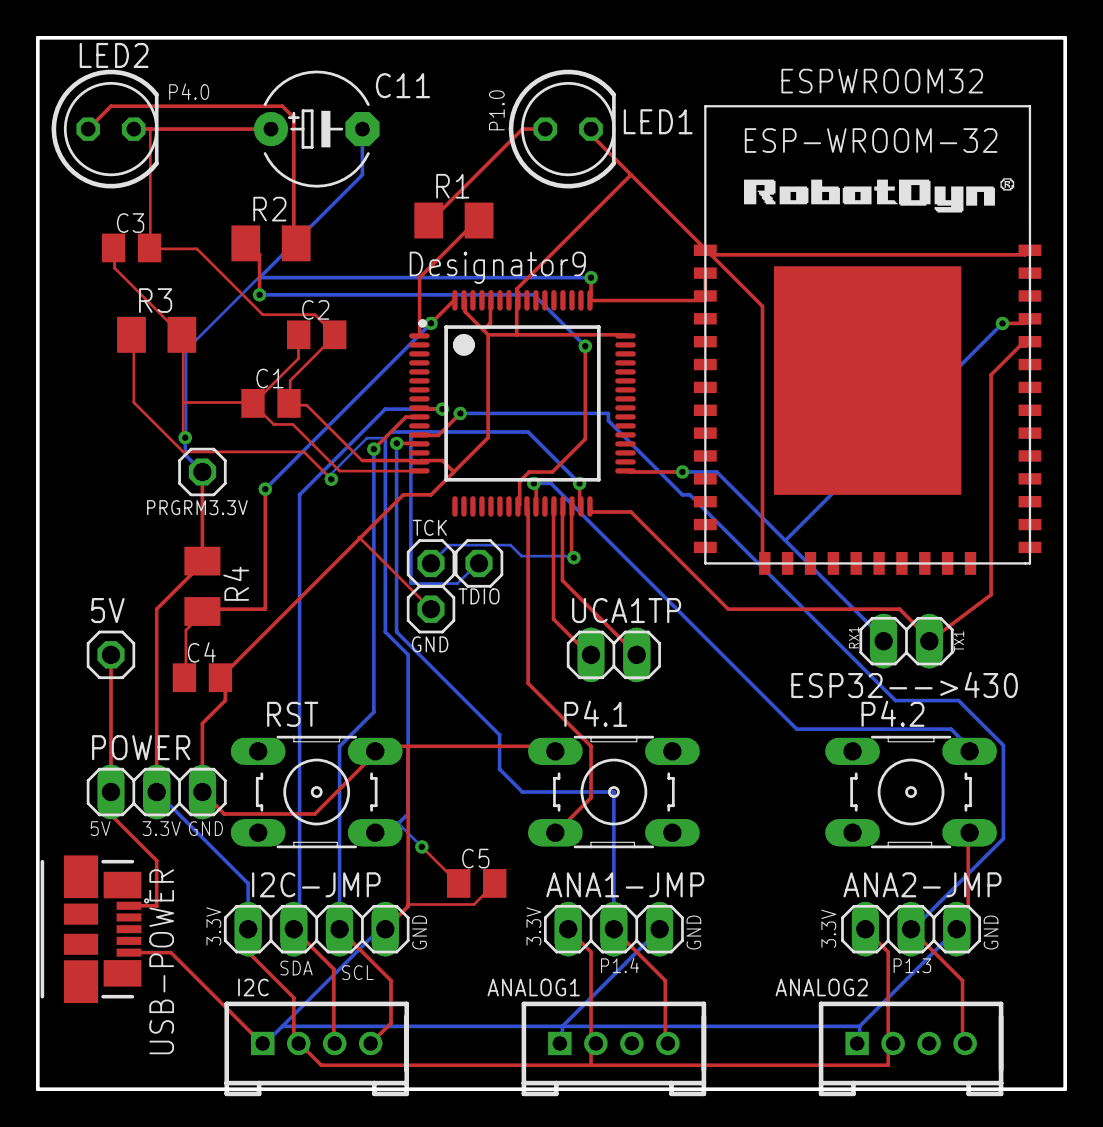
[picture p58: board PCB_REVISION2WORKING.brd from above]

Board: 2 copper layers, 57.1 x 58.4 mm, 32 parts (0 on the bottom side), 20 nets.

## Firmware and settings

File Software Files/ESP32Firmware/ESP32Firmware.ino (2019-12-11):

// Copyright (c) Microsoft. All rights reserved.
// Licensed under the MIT license.

#include <WiFi.h>
#include "AzureIotHub.h"
#include "Esp32MQTTClient.h"

#include <BLEDevice.h>
#include <BLEServer.h>
#include <BLEUtils.h>
#include <BLE2902.h>

#define DEVICE_ID "Esp32Device"
#define MESSAGE_MAX_LEN 256

#define SERVICE_UUID           "6E400001-B5A3-F393-E0A9-E50E24DCCA9E" // UART service UUID
#define CHARACTERISTIC_UUID_RX "6E400002-B5A3-F393-E0A9-E50E24DCCA9E"
#define CHARACTERISTIC_UUID_TX "6E400003-B5A3-F393-E0A9-E50E24DCCA9E"

// Non volatile variables
RTC_DATA_ATTR int baud_rate = 115200;

RTC_DATA_ATTR char ssid[256] = "\0";
RTC_DATA_ATTR char password[256] = "\0";
//

// BLE stuff
BLEServer *pServer = NULL;
BLECharacteristic * pTxCharacteristic;
bool deviceConnected = false;
bool oldDeviceConnected = false;
RTC_DATA_ATTR bool wifiMode = false;
//

String inputString = "";
bool commandReady = false;

/*String containing Hostname, Device Id & Device Key in the format:                         */
/*  "HostName=<host_name>;DeviceId=<device_id>;SharedAccessKey=<device_key>"                */
/*  "HostName=<host_name>;DeviceId=<device_id>;SharedAccessSignature=<device_sas_token>"    */
RTC_DATA_ATTR char connectionString[256] = "\0";

const char *messageData = "{\"deviceId\":\"%s\", \"messageId\":%d, \"%s\":%s}";

int messageCount = 1;
RTC_DATA_ATTR bool hasSSID = false;
RTC_DATA_ATTR bool hasPass = false;
RTC_DATA_ATTR bool hasConnectionString = false;
static bool hasWifi = false;
static bool messageSending = true;
static uint64_t send_interval_ms;


//////////////////////////////////////////////////////////////////////////////////////////////////////////
// BLE Stuff
class MyServerCallbacks: public BLEServerCallbacks {
    void onConnect(BLEServer* pServer) {
      deviceConnected = true;
    };

    void onDisconnect(BLEServer* pServer) {
      deviceConnected = false;
    }
};

class MyCallbacks: public BLECharacteristicCallbacks {
    void onWrite(BLECharacteristic *pCharacteristic) {
      std::string rxValue = pCharacteristic->getValue();

      if (rxValue.length() > 0) {
        Serial.println("*********");
        Serial.print("Received Value: ");
        for (int i = 0; i < rxValue.length(); i++)
          Serial.print(rxValue[i]);

        Serial.println();
        Serial.println("*********");
      }
    }
};

//////////////////////////////////////////////////////////////////////////////////////////////////////////
// Utilities
static void InitWifi()
{
  Serial.println("Connecting...");
  WiFi.begin((const char*)ssid, (const char*)password);
  int count = 0;
  while (WiFi.status() != WL_CONNECTED) {
    delay(500);
    Serial.print(".");
    if (++count > 20) {
      Serial.println("ERR: Could not connect");
      hasWifi = false;
      return;
    }
  }
  hasWifi = true;
  Serial.println("WiFi connected");
  Serial.println("IP address: ");
  Serial.println(WiFi.localIP());
}

static void SendConfirmationCallback(IOTHUB_CLIENT_CONFIRMATION_RESULT result)
{
  if (result == IOTHUB_CLIENT_CONFIRMATION_OK)
  {
    Serial.println("Send Confirmation Callback finished.");
  }
}

static void MessageCallback(const char* payLoad, int size)
{
  Serial.println("Message callback:");
  Serial.println(payLoad);
}

static void DeviceTwinCallback(DEVICE_TWIN_UPDATE_STATE updateState, const unsigned char *payLoad, int size)
{
  char *temp = (char *)malloc(size + 1);
  if (temp == NULL)
  {
    return;
  }
  memcpy(temp, payLoad, size);
  temp[size] = '\0';
  // Display Twin message.
  Serial.println(temp);
  free(temp);
}

static int  DeviceMethodCallback(const char *methodName, const unsigned char *payload, int size, unsigned char **response, int *response_size)
{
  LogInfo("Try to invoke method %s", methodName);
  const char *responseMessage = "\"Successfully invoke device method\"";
  int result = 200;

  if (strcmp(methodName, "start") == 0)
  {
    LogInfo("Start sending temperature and humidity data");
    messageSending = true;
  }
  else if (strcmp(methodName, "stop") == 0)
  {
    LogInfo("Stop sending temperature and humidity data");
    messageSending = false;
  }
  else
  {
    LogInfo("No method %s found", methodName);
    responseMessage = "\"No method found\"";
    result = 404;
  }

  *response_size = strlen(responseMessage) + 1;
  *response = (unsigned char *)strdup(responseMessage);

  return result;
}

void readToEndChar(char terminal, char* string) {
  int i = 0;
  while (1) {
    if (Serial.available() > 0) {
      string[i] = Serial.read();
      if (string[i] == terminal) {
        string[i] = '\0';
        break;
      }
      i++;
    }
  }
}

void initAzure() {
  Esp32MQTTClient_SetOption(OPTION_MINI_SOLUTION_NAME, "GetStarted");
  Esp32MQTTClient_Init((const uint8_t*)connectionString, true);

  Esp32MQTTClient_SetSendConfirmationCallback(SendConfirmationCallback);
  Esp32MQTTClient_SetMessageCallback(MessageCallback);
  Esp32MQTTClient_SetDeviceTwinCallback(DeviceTwinCallback);
  Esp32MQTTClient_SetDeviceMethodCallback(DeviceMethodCallback);
}

void initBLE() {
  // Create the BLE Device
  BLEDevice::init("ESP32 BLE");

  // Create the BLE Server
  pServer = BLEDevice::createServer();
  pServer->setCallbacks(new MyServerCallbacks());

  // Create the BLE Service
  BLEService *pService = pServer->createService(SERVICE_UUID);

  // Create a BLE Characteristic
  pTxCharacteristic = pService->createCharacteristic(
                        CHARACTERISTIC_UUID_TX,
                        BLECharacteristic::PROPERTY_NOTIFY
                      );

  pTxCharacteristic->addDescriptor(new BLE2902());

  BLECharacteristic * pRxCharacteristic = pService->createCharacteristic(
      CHARACTERISTIC_UUID_RX,
      BLECharacteristic::PROPERTY_WRITE
                                          );

  pRxCharacteristic->setCallbacks(new MyCallbacks());

  // Start the service
  pService->start();

  // Start advertising
  pServer->getAdvertising()->start();
  Serial.println("Waiting a client connection to notify...");
}

//////////////////////////////////////////////////////////////////////////////////////////////////////////
// Arduino sketch
void setup()
{
  Serial.begin(baud_rate);
  Serial.println("ESP32 Device");
  Serial.println("Initializing...");
  initBLE();
  hasWifi = false;
  if (hasSSID && hasPass && wifiMode) {
    InitWifi();
    if(connectionString[0] != '\0'){
      initAzure();
    }
  }
  randomSeed(analogRead(0));
  send_interval_ms = millis();
}

void loop()
{
  while (Serial.available()) {
    //
    char inChar = (char)Serial.read();
    //
    inputString += inChar;
    //
    if (inChar == '\r') {
      commandReady = true;
    }
  }

  if (commandReady) {
    commandReady = false;
    int i;
    int j = 0;
    char command[256];
    for (i = 0; inputString[i] != '\0'; i++) {
      command[i] = inputString[i];
    }
    command[i] = '\0';
    Serial.println(command);
    inputString = "";
    if (!strcmp("AT\r", command)) {
      Serial.println("OK");
    } else if (!strncmp("AT+ssid\r", (const char*)command, 8)) {
      Serial.println(ssid);
      Serial.println("OK");
    } else if (!strncmp("AT+ssid=", (const char*)command, 8)) {
      for (i = 8; command[i] != '\r'; i++) {
        ssid[j++] = command[i];
      }
      ssid[j] = '\0';
      hasSSID = true;
      Serial.println("OK");
      if (hasSSID && hasPass) {
        InitWifi();
      }
    } else if (!strncmp("AT+pass\r", (const char*)command, 8)) {
      Serial.println(password);
      Serial.println("OK");
    } else if (!strncmp("AT+pass=", (const char*)command, 8)) {
      for (i = 8; command[i] != '\r'; i++) {
        password[j++] = command[i];
      }
      password[j] = '\0';
      hasPass = true;
      Serial.println("OK");
      if (hasSSID && hasPass) {
        InitWifi();
      }
    } else if (!strncmp("AT+connString\r", command, 14)) {
      Serial.println(connectionString);
      Serial.println("OK");
    } else if (!strncmp("AT+connString=", command, 14)) {
      for (i = 14; command[i] != '\r'; i++) {
        connectionString[j++] = command[i];
      }
      connectionString[j] = '\0';
      initAzure();
      Serial.println("OK");
    } else if (!strncmp("AT+telemetry=", command, 13)) {
      char telemetry[32];
      for (i = 13; command[i] != ','; i++) {
        telemetry[j++] = command[i];
      }
      telemetry[j] = '\0';
      j = 0;
      char value[32];
      i++;
      while (command[i] != '\r') {
        value[j++] = command[i++];
      }
      value[j] = '\0';
      if (wifiMode) {
        char messagePayload[MESSAGE_MAX_LEN];
        snprintf(messagePayload, MESSAGE_MAX_LEN, messageData, DEVICE_ID, messageCount++, telemetry, value);
        if (hasWifi) {
          if (messageSending) {
            Serial.println(messagePayload);
            EVENT_INSTANCE* message = Esp32MQTTClient_Event_Generate(messagePayload, MESSAGE);
            Esp32MQTTClient_Event_AddProp(message, "temperatureAlert", "true");
            Esp32MQTTClient_SendEventInstance(message);
            send_interval_ms = millis();
            Serial.println("OK");
          }
          else {
            Esp32MQTTClient_Check();
          }
        } else {
          Serial.println("ERR: No wifi");
        }
      }
      else {
        char ble_message[32];
        sprintf(ble_message, "%s=%s", telemetry, value);
        Serial.println(ble_message);
        if (deviceConnected) {
          pTxCharacteristic->setValue(ble_message);
          pTxCharacteristic->notify();
          Serial.println("OK");
        } else {
          Serial.println("ERR: Device not connected");
        }
      }
    } else if (!strncmp("AT+mode\r", command, 8)) {
      if (wifiMode) {
        Serial.println("0: WiFi mode");
      } else {
        Serial.println("1: BLE mode");
      }
      Serial.println("OK");
    } else if (!strncmp("AT+mode=", command, 8)) {
      if (command[8] == '0') {
        wifiMode = true;
        if (hasSSID && hasPass) {
          InitWifi();
          if (hasWifi) {
            initAzure();
          }
        }
      } else if (command[8] == '1') {
        wifiMode = false;
      } else {
        Serial.println("?");
        return;
      }
      Serial.println("OK");
    } else if (!strncmp("AT+baud=", command, 8)) {
      String baud_rate_str = "";
      for (i = 8; command[i] != '\r'; i++) {
        baud_rate_str += command[i];
      }
      baud_rate = baud_rate_str.toInt();
      Serial.printf("Changing baud rate to %d\n", baud_rate);
      delay(50);
      Serial.begin(baud_rate);
      delay(50);
      Serial.printf("Baud rate is now %d\n", baud_rate);
      Serial.println("OK");
    } else if (!strncmp("AT+sleep=", command, 9)) {
      String timer = "";
      for (i = 9; command[i] != '\r'; i++) {
        timer += command[i];
      }
      int timer_int = timer.toInt();
      esp_sleep_enable_timer_wakeup(timer_int * 1000000);
      Serial.printf("ESP32 set to sleep for %d seconds\n", timer_int);
      Serial.println("Going to sleep now");
      Serial.flush();
      esp_deep_sleep_start();
    } else {
      Serial.println("?");
      return;
    }

  }
  // disconnecting
  if (!deviceConnected && oldDeviceConnected) {
    delay(500); // give the bluetooth stack the chance to get things ready
    pServer->startAdvertising(); // restart advertising
    Serial.println("start advertising");
    oldDeviceConnected = deviceConnected;
  }
  // connecting
  if (deviceConnected && !oldDeviceConnected) {
    // do stuff here on connecting
    oldDeviceConnected = deviceConnected;
  }
}

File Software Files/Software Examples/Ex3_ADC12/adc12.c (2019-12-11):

//******************************************************************************
//  MSP430FR5994 Demo - ADC12B, Sample A1, AVcc Ref, Set P1.0 if A1 > 0.5*AVcc
//              Converts 12-bit integer into string representation of percentage
//
//   Description: A single sample is made on A1 with reference to AVcc.
//   Software sets ADC12BSC to start sample and conversion - ADC12BSC
//   automatically cleared at EOC. ADC12B internal oscillator times sample (16x)
//   and conversion. If A0 > 0.5*AVcc, P1.0 set, else reset. The full, correct handling of
//   and ADC12B interrupt is shown as well. A string representation of the
//	 percentage out of 2^12 is constructed.
//
//
//                MSP430FR5969
//             -----------------
//         /|\|                 |
//          | |                 |
//          --|RST              |
//            |                 |
//        >---|P1.4/A4      P1.0|-->LED
//
//******************************************************************************
#include "driverlib.h"
#include <stdio.h>

#define MAXIMUM (1000)

// Global variable
uint16_t ADC_value;

// Function declaration
void ADC_getPercentage(uint8_t buffer[], uint16_t value, uint16_t maximum);

void main(void) {
	// Stop WDT
	WDT_A_hold(WDT_A_BASE);

	//Set P1.0 as an output pin.
	/*

	 * Select Port 1
	 * Set Pin 0 as output
	 */
	GPIO_setAsOutputPin( GPIO_PORT_P1, GPIO_PIN0);

	//Set P1.0 as Output Low.
	/*

	 * Select Port 1
	 * Set Pin 0 to output Low.
	 */
	GPIO_setOutputLowOnPin( GPIO_PORT_P1, GPIO_PIN0);
	//Set P1.4 as Ternary Module Function Output.
	/*

	 * Select Port 1
	 * Set Pin 4 to output Ternary Module Function, (A4, C4, VREF+, VeREF+).
	 */
	GPIO_setAsPeripheralModuleFunctionOutputPin(GPIO_PORT_P1, GPIO_PIN4,
	GPIO_TERNARY_MODULE_FUNCTION);

	/*
	 * Disable the GPIO power-on default high-impedance mode to activate
	 * previously configured port settings
	 */
	PMM_unlockLPM5();

	//Initialize the ADC12B Module
	/*
	 * Base address of ADC12B Module
	 * Use internal ADC12B bit as sample/hold signal to start conversion
	 * USE MODOSC 5MHZ Digital Oscillator as clock source
	 * Use default clock divider/pre-divider of 1
	 * Not use internal channel
	 */
	ADC12_B_initParam initParam = { 0 };
	initParam.sampleHoldSignalSourceSelect = ADC12_B_SAMPLEHOLDSOURCE_SC;
	initParam.clockSourceSelect = ADC12_B_CLOCKSOURCE_ADC12OSC;
	initParam.clockSourceDivider = ADC12_B_CLOCKDIVIDER_1;
	initParam.clockSourcePredivider = ADC12_B_CLOCKPREDIVIDER__1;
	initParam.internalChannelMap = ADC12_B_NOINTCH;
	ADC12_B_init(ADC12_B_BASE, &initParam);

	//Enable the ADC12B module
	ADC12_B_enable(ADC12_B_BASE);

	/*
	 * Base address of ADC12B Module
	 * For memory buffers 0-7 sample/hold for 64 clock cycles
	 * For memory buffers 8-15 sample/hold for 4 clock cycles (default)
	 * Disable Multiple Sampling
	 */
	ADC12_B_setupSamplingTimer(ADC12_B_BASE, ADC12_B_CYCLEHOLD_16_CYCLES,
			ADC12_B_CYCLEHOLD_4_CYCLES, ADC12_B_MULTIPLESAMPLESDISABLE);

	//Configure Memory Buffer
	/*
	 * Base address of the ADC12B Module
	 * Configure memory buffer 0
	 * Map input A1 to memory buffer 0
	 * Vref+ = AVcc
	 * Vref- = AVss
	 * Memory buffer 0 is not the end of a sequence
	 */
	ADC12_B_configureMemoryParam configureMemoryParam = { 0 };
	configureMemoryParam.memoryBufferControlIndex = ADC12_B_MEMORY_0;
	configureMemoryParam.inputSourceSelect = ADC12_B_INPUT_A4;
	configureMemoryParam.refVoltageSourceSelect =
			ADC12_B_VREFPOS_AVCC_VREFNEG_VSS;
	configureMemoryParam.endOfSequence = ADC12_B_NOTENDOFSEQUENCE;
	configureMemoryParam.windowComparatorSelect =
			ADC12_B_WINDOW_COMPARATOR_DISABLE;
	configureMemoryParam.differentialModeSelect =
			ADC12_B_DIFFERENTIAL_MODE_DISABLE;
	ADC12_B_configureMemory(ADC12_B_BASE, &configureMemoryParam);

	ADC12_B_clearInterrupt(ADC12_B_BASE, 0, ADC12_B_IFG0);

	//Enable memory buffer 0 interrupt
	ADC12_B_enableInterrupt(ADC12_B_BASE, ADC12_B_IE0, 0, 0);
	__enable_interrupt();

	while (1) {
		__delay_cycles(5000);

		//Enable/Start sampling and conversion
		/*
		 * Base address of ADC12B Module
		 * Start the conversion into memory buffer 0
		 * Use the single-channel, single-conversion mode
		 */
		ADC12_B_startConversion(ADC12_B_BASE, ADC12_B_MEMORY_0,
		ADC12_B_SINGLECHANNEL);
		uint8_t percentage[8];
		ADC_getPercentage(percentage, ADC_value, 1000);

	}
}

#pragma vector=ADC12_VECTOR
__interrupt
void ADC12_ISR(void) {
	switch (__even_in_range(ADC12IV, 12)) {
	case 0:
		break;                         // Vector  0:  No interrupt
	case 2:
		break;                         // Vector  2:  ADC12BMEMx Overflow
	case 4:
		break;                         // Vector  4:  Conversion time overflow
	case 6:
		break;                         // Vector  6:  ADC12BHI
	case 8:
		break;                         // Vector  8:  ADC12BLO
	case 10:
		break;                         // Vector 10:  ADC12BIN
	case 12:                                // Vector 12:  ADC12BMEM0 Interrupt
		ADC_value = ADC12_B_getResults(ADC12_B_BASE, ADC12_B_MEMORY_0);
		if (ADC_value >= (MAXIMUM/2) ) {
			//Set P1.0 LED on
			/*

			 * Select Port 1
			 * Set Pin 0 to output high.
			 */
			GPIO_setOutputHighOnPin( GPIO_PORT_P1, GPIO_PIN0);
		} else {
			//Set P1.0 LED off
			/*
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

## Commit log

2019-12-11 added enclosure
    [BackSide.SLDPRT, BackSide.STL, Bottom.SLDPRT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]
2019-12-12 Final commit
    [PCB_REVISION2WORKING.brd, PCB_REVISION2WORKING.sch]
